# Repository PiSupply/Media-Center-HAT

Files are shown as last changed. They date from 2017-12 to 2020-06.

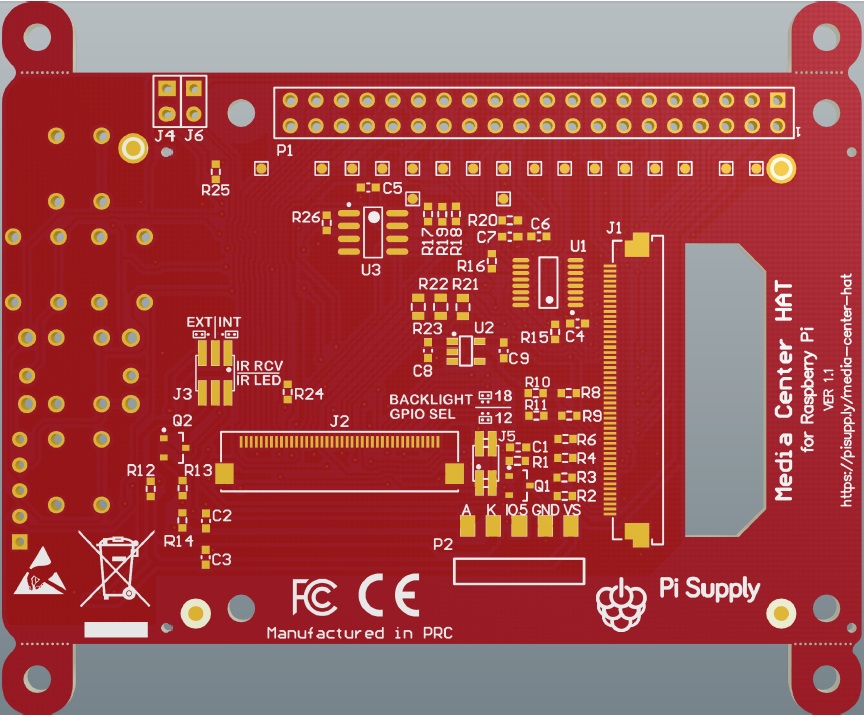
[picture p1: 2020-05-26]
Hardware/Production/MC_HAT_bottom.jpg

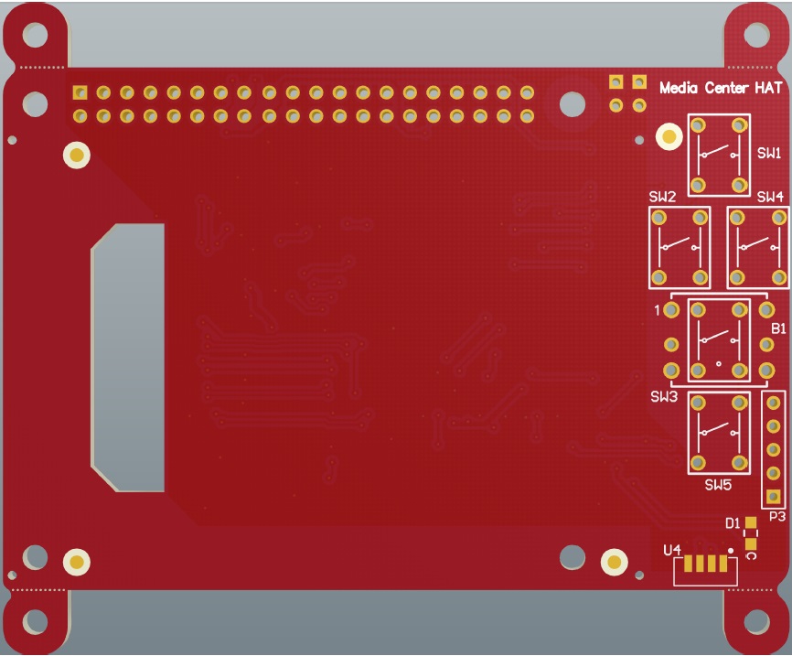
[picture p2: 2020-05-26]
Hardware/Production/MC_HAT_top.jpg

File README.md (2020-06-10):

Media-Center-HAT-Banner
# Media Center HAT
Media-Center-HAT

Take your entertainment with the Raspberry Pi to the next level with the Media Center HAT. Build a full-featured media center capable of playing nearly all of your digital media using any 40-pin Raspberry Pi computer and the Media Center HAT. Native support in OSMC and LibreELEC and other media center operating systems brings plug-n-play compatibility and the 2.83" resistive touchscreen, optional 5-way programmable joystick and included IR remote gives you 3-ways to control your content. Flexible mounting options let you position the HAT for use as is or in an enclosure. Create the Raspberry Pi powered media center you've always wanted with the Media Center HAT.

# Set Up Media Center HAT
## Auto Installation
Just run the following script in a terminal window and the Media Center HAT will be automatically setup.
```bash
# Run this line and the Media Center HAT will be setup and installed
sudo su -c "bash <(wget -qO- https://pisupp.ly/mediacentersoftware)" root
```

Please check the [software](https://github.com/PiSupply/Media-Center-HAT/blob/master/Software) or the [Hardware](https://github.com/PiSupply/Media-Center-HAT/blob/master/Hardware) sections for further information.

# Thank you!

This software and product is based on and uses a number of open source libraries and we wanted to thank the creators here. This product wouldn't be possible without their efforts!

- [Notro FBTFT](https://github.com/notro/fbtft/wiki)
- [Watterott RPi-Display](https://github.com/watterott/RPi-Display)
- [Lirc](http://www.lirc.org/)

# License

Creative Commons Licence

This work is licensed under a [Creative Commons Attribution-ShareAlike 4.0 International License](http://creativecommons.org/licenses/by-sa/4.0/).

## Open Source Hardware

We are proud to say that the Media Center HAT is certified by the [Open Source Hardware Association](https://certification.oshwa.org/uk000009.html) with UID number UK000009. Our certification mark is below:



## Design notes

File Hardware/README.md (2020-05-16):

# Hardware
MCH_Overview MCH Overview

## Switches

### Buttons

*Please note the the 5 ways joystick is alternative to the various push buttons SW1-5 and therefore is connected to the same GPIO pins on the Raspberry Pi.*

* **SW1** GPIO13(PI33) up
* **SW2** GPIO17(PI11) left
* **SW3** GPIO22(PI15) bottom
* **SW4** GPIO26(PI37) right
* **SW5** GPIO27(PI13) enter
* **B1** 5 ways joystick

## Connectors

### Top of the board

* **P3** External rotary encoder

### Bottom of the board

* **P2** External IR receiver and LED
  * **VS** 3.3V source for external IR receiver,
  * **GND** ground connection for external IR receiver,
  * **GPIO5(PI29)** input for external IR receiver,
  * **K** cathode connection for external IR LED transmitter,
  * **A** 5V source for external IR LED transmitter, connects to anode

* **J1** Display connector
* **J2** GPIO adapter

## Jumpers

* **J3** IR selection jumper, on board or external.
    * **1-3** Internal IR receiver
    * **3-5** External IR receiver
    * **2-4** Internal IR LED
    * **4-6** External IR LED
* **J4** ID EEPROM write protect disable jumper. Short to write to EEPROM.
* **J5** Backlight control GPIO selection jumper, GPIO18(PI12) or GPIO12(PI32). The GPIO controlling the backlight defaults to GPIO12 so that the MCH can be used in conjunction with an audio board using I2S like in the case of JustBoom Audio, HiFiBerry, iQaudio, etc.
* **J6** Change ID EEPROM address from 0x50 to 0x51. Short or install a 2 pin header with a jumper to change address to 0x51.

## Pinout

#### P1 pinout
```text
P1
-----------------------------------------------------------------------------------------------------------------------
| 2     4     6     8    10    12    14    16    18    20    22    24    26    28    30    32    34    36    38    40 |
|5V    5V    GND   o     o     +     GND   #     #     GND   #     o     o     #     GND   +     GND   o     o     o  |
|3V3   o     o     o     GND   +     +     +     3V3   o     o     o     GND   #     #     #     +     o     +     GND|
| 1     3     5     7     9    11    13    15    17    19    21    23    25    27    29    31    33    35    37    39 |
-----------------------------------------------------------------------------------------------------------------------

# Used
o Available
+ Can be reused

11 SW1
12 Backlight control
13 SW5
15 SW3
16 Display reset
18 Display Read/Write control
22 Touch controller interrupt signal
27 I2C_SDA to HAT EEPROM
28 I2C_SDL to HAT EEPROM
29 IR Receiver
31 IR Transmitter
32 Backlight control
33 SW1
37 SW4
```

#### P2 Pinout
```text
P2
-------------------------------
| 1     2     3     4     5   |
|VSYS  GND   PI29   K     A   |
-------------------------------
```

#### P3 Pinout
```text
P3
-------------------------------
| 1     2     3     4     5   |
|GND   3V3   PI13  PI15  PI37 |
-------------------------------
```

#### J2 Pinout
```text
J2
------------------------------------------------------------------------------------------------------------------------------------------------------------------------------------------------------------------------------------------------------------
| 1     2     3     4     5     6     7     8     9    10    11    12    13    14    15    16    17    18    19    20    21    22    23    24    25    26    27    28    29    30    31    32    33    34    35    36    37    38    39    40    MF1   MF2 |
|3V3   5V    SDA   5V    SCL   GND   PI7   PI8   GND  PI10  PI11  PI12  PI13  PI14  PI15  PI16   3V3  PI18  PI19   GND  PI21  PI22  PI23  PI24   GND  PI26  PI27  PI28  PI29   GND  PI31  PI32  PI33   GND  PI35  PI36  PI37  PI38   GND  PI40   GND   GND |
------------------------------------------------------------------------------------------------------------------------------------------------------------------------------------------------------------------------------------------------------------
```

#### J3 Pinout
```text
J3
-----------------
| 2     4     6 |
|INT  IRLED  EXT|
|INT  IRREC  EXT|
| 1     3     5 |
-----------------
```

#### J4 Pinout
```text
J4
-------------
| 1     2   |
|3V3   A2/A1|
-------------
```

#### J5 Pinout
```text
J5
------------
| 2     4  |
|PI12   BL |
|PI32   BL |
| 1     3  |
------------
```

#### J6 Pinout
```text
J6
------------
| 1     2  |
|3V3   A0  |
------------
```

#### B1 Pinout
```text
B1
------------------
| 6     5     4  |
|PI13  PI37  GND |
|PI33  PI11  PI15|
| 1     2     3  |
------------------
```

#### TP Pinout
```text
TP
------------------------------------------------------------------------------------------------------------
| 1     2     3     4     5     6     7     8     9    10    11    12    13    14    15    16    17    18  |
|GND   5V    3V3   MOSI  MISO  SCK LCD_CS SEN_CS PI12 PI16  PI18  PI29  PI31 ID_SCL ID_SDA EWP  PI22  PI32 |
------------------------------------------------------------------------------------------------------------
```

## Components

### Main active components

Main ICs

The picture above highlights the main ICs used on the Media Center HAT. Links to the various datasheets have been provided in line with the description.

1. **Display** [MI0283QT](https://github.com/PiSupply/Media-Center-HAT/blob/master/Hardware/Datasheets/MI0283QT-11_Ver1.4.pdf) 2.8" TFT Display(320x240)with Touchpanel.
2. **Touch screen controller** [ADS7846](https://github.com/PiSupply/Media-Center-HAT/blob/master/Hardware/Datasheets/ads7846.pdf) 4-wire touch screen controller.
3. **IR Rcv Module** [TSOP75238W](https://github.com/PiSupply/Media-Center-HAT/blob/master/Hardware/Datasheets/TSOP75238W.pdf) miniaturised SMD IR receiver for infrared remote control systems.
4. **EEPROM** [CAT24C32](https://github.com/PiSupply/Media-Center-HAT/blob/master/Hardware/Datasheets/CAT24C32-D.PDF)  EEPROM, I2C, 32KBIT, 400KHZ, 1V7-5V5

### Unpopulated

You may notice that there are several components which have not be installed on your board. This section aims to explain what they are and which are for user customisation.

* **TPx** these are all test points used to test the boards during manufacturing. Refer to the pinout above for more information.

* **R20** this is hardware configuration of reference input to touch interface chip. This is not important to users. How would use this, if necessary?

* **R21, R22 and R23** It is about to have better signal integrity on high frequency SPI lines by cutting off side connection to header and cable if there for any purpose.
R21, R22 and R23 should be populated if the HAT is connected through J2 40 FPC header to the Raspberry Pi via GPIO adaptor board. These can be zero Ohm resistors or just solder shorts.
    * **R21** SPI MOSI, connects RPI MOSI GPIO to equivalent pin 19 of J2 FPC header,
    * **R22** SPI MISO, connects RPI MISO GPIO to equivalent pin 21 of J2 FPC header,
    * **R23** SPI SCK, connects RPI CLK GPIO to equivalent pin 23 of J2 FPC header.

* **R9, R10** Used for display interface selection.
  * **Unpopulated** default, 4-wire 8-bit data serial SPI interface,
  * **Both populated** 3-wire 9-bit data serial SPI interface.

## Misc
It is possible that EEPROM is not programmed, or is programmed with different DT which does not match GPIO selection jumper default configuration (GPIO12).

The EEPROM should be programmed using dtbo for GPIO12 file from drive. They can try to switch gpio sel jumper to position 18 and see if it works. If not they can try to
enable device tree in config.txt by putting SD into PC, adding two lines:

```text
dtoverlay=gpio-ir,gpio_pin=5
dtoverlay=rpi-display,speed=32000000,rotate=90
```

No additional pullups and resistors on board for buttons/joystick/encoder, just ones enabled at gpio rpi ports. It should be configured as pullups for these, because button on schematic is connected to gnd. Placing additional resistors may constrain to use that gpios for other gpio functions like LEDs or some other output control...so we decided to omit these from the design, to make it more useful in a wider array of use cases. Because of this, you can use the button inputs to just connect to the various GPIO pins for other purposes as well.

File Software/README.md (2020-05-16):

# Media Centre HAT Software

## Software Installation

**NOTE:** When using the Media Center HAT with the PiJuice HAT you will need to change the ID EEPROM address on the PiJuice to 0x52 otherwise both HAT's will conflict with each other and the Media Center HAT will not load the DT overlay file.

### Automated process

Just run the following script in a terminal window and the Media Center HAT will be automatically setup.
```bash
# Run this line and the Media Center HAT will be setup and installed
sudo su -c "bash <(wget -qO- https://pisupp.ly/mediacentersoftware)" root
```

alternatively from the command line:

```bash
git clone https://github.com/PiSupply/Media-Center-HAT.git
sudo bash Media-Centre-HAT/Software/install.sh
```

#### Screen Orientation
```text
Select one of the options below:
[0] - Portrait
[90] - Horizontal (Default)
[180] - Portrait Reverse
[270] - Horizontal Reverse
```
Reply with one of the following values: 0, 90, 180, 270

#### TFT Driver
```text
--- Updating /boot/config.txt ---

Please reboot the system after the installation.

--- Updating /etc/X11/xorg.conf.d ---

-layout TFT
-layout HDMI
-layout HDMITFT
When -layout is not set, the first is used: TFT
```

#### Console
```text
Activate the console on the TFT display? y/n
```
Reply with "Y"

#### Framebuffer (fbcp)
```text
Install fbcp (Framebuffer Copy)? y/n
```
Reply with "Y"

```text
To enable automatic startup of fbcp run:
sudo update-rc.d fbcp defaults
To disable automatic startup of fbcp run:
sudo update-rc.d fbcp remove
```

```text
Enable automatic startup of fbcp on boot? y/n
```
Reply with "Y"

```text
Note: The console output on the TFT display will be disabled.
Set screen blanking time to 10 minutes.
```

#### xinput-calibrator
```text
Install xinput-calibrator? y/n
```
Reply with "Y"

#### Joystick/buttons
```text
Enable onboard Joystick/Buttons? y/n
```
Reply with "Y"

#### MCH IR Remote
```text
Configure MCH IR Remote? y/n
```
Reply with "Y"

#### Reboot
```text
Reboot the system now? y/n
```
Reply with "Y"

### Manual process

#### Changing the screen orientation
If you wish to change the screen orientation without running the installation script you can change the following line in `/boot/config.txt`:

```text
dtoverlay=media-center,speed=32000000,rotate=0
```

and change rotate to 0, 90, 180 or 270.

#### Configure video driver
fbdev is an Xorg driver for framebuffer devices. You need to edit the file `/usr/share/X11/xorg.conf.d` and add the following:
```text
Section "ServerLayout"
    Identifier "TFT"
    Option "BlankTime" "10"
    Screen 0 "ScreenTFT"
EndSection

Section "ServerLayout"
    Identifier "HDMI"
    Option "BlankTime" "10"
    Screen 0 "ScreenHDMI"
EndSection

Section "ServerLayout"
    Identifier "HDMITFT"
    Option "BlankTime" "10"
    Screen 0 "ScreenHDMI"
    Screen 1 "ScreenTFT" RightOf "ScreenHDMI"
#   Screen 1 "ScreenTFT" LeftOf "ScreenHDMI"
#   Screen 1 "ScreenTFT" Above "ScreenHDMI"
#   Screen 1 "ScreenTFT" Below "ScreenHDMI"
#   Screen 1 "ScreenTFT" Relative "ScreenHDMI" x y
#   Screen 1 "ScreenTFT" Absolute x y
EndSection

Section "Screen"
    Identifier "ScreenHDMI"
    Monitor "MonitorHDMI"
    Device "DeviceHDMI"
Endsection

Section "Screen"
    Identifier "ScreenTFT"
    Monitor "MonitorTFT"
    Device "DeviceTFT"
Endsection

Section "Monitor"
    Identifier "MonitorHDMI"
Endsection

Section "Monitor"
    Identifier "MonitorTFT"
Endsection

Section "Device"
    Identifier "DeviceHDMI"
    Driver "fbturbo"
    Option "fbdev" "/dev/fb0"
    Option "SwapbuffersWait" "true"
EndSection

Section "Device"
    Identifier "DeviceTFT"
    Driver "fbturbo"
    Option "fbdev" "/dev/fb1"
EndSection
EOF
```
#### Touchscreen configuration
Edit the file `/usr/share/X11/xorg.conf.d/99-ads7846-cal.conf` and add the following:
```text
Section "InputClass"
  Identifier "calibration"
  MatchProduct "ADS7846 Touchscreen"
  Option "EmulateThirdButton" "1"
  Option "EmulateThirdButtonButton" "3"
  Option "EmulateThirdButtonTimeout" "1500"
  Option "EmulateThirdButtonMoveThreshold" "30"
  Option "InvertX" "$invertx"
  Option "InvertY" "$inverty"
  Option "SwapAxes" "$swapaxes"
  Option "TransformationMatrix" "$tmatrix"
EndSection
EOF
```
Where $invertx, inverty, $swapaxes and $tmatrix is replace with one of the following values depending on the screen orientation:
```text
0 degrees (Portrait)
invertx="0"
inverty="0"
swapaxes="0"
tmatrix="1 0 0 0 1 0 0 0 1"

90 degrees (Horizontal (Default))
invertx="1"
inverty="0"
swapaxes="1"
tmatrix="0 -1 1 1 0 0 0 0 1"

180 degrees (Portrait reverse)
invertx="1"
inverty="1"
swapaxes="0"
tmatrix="-1 0 1 0 -1 1 0 0 1"

270 degrees (Horizontal reverse)
invertx="0"
inverty="1"
swapaxes="1"
tmatrix="0 1 0 -1 0 1 0 0 1"
```

#### Install Xinput Calibrator
Xinput calibrator can be used to fine tune the touchscreen calibration for the screen.

```bash
sudo apt-get install xinput-calibrator -y
```

Point the values recorded of Xinput calibrator to `99-ads7846-cal.conf` file by editing `/etc/X11/Xsession.d/xinput_calibrator_pointercal` and adding the following:
```text
#!/bin/sh
PATH="/usr/bin:$PATH"
BINARY="xinput_calibrator"
CALFILE="/usr/share/X11/xorg.conf.d/99-ads7846-cal.conf"
LOGFILE="/var/log/xinput_calibrator.pointercal.log"

CALDATA=`grep -o 'Option[[:space:]]*"MinX".*' $CALFILE`
if [ ! -z "$CALDATA" ] ; then
    echo "Using calibration data stored in $CALFILE"
    exit 0
fi

CALDATA=`DISPLAY=:0.0 $BINARY --output-type xorg.conf.d --device 'ADS7846 Touchscreen' | tee $LOGFILE | grep -i 'MinX\|MaxX\|MinY\|MaxY'`
if [ ! -z "$CALDATA" ] ; then
    sed -i "/MinX/d;/MaxX/d;/MinY/d;/MaxY/d;/EndSection/d" "$CALFILE"
    cat >> "$CALFILE" <<EOD
$CALDATA
EndSection
EOD
    echo "Calibration data stored in $CALFILE (log in $LOGFILE)"
fi
EOF
```

Add touchpanel calibration to startup by editing `/etc/xdg/lxsession/LXDE-pi/autostart` and add the following line:
```text
sudo /bin/sh /etc/X11/Xsession.d/xinput_calibrator_pointercal
```
#### Update lightdm for Buster
Raspbian Buster uses lightdm to control the X server. We need to edit the `/etc/lightdm/lightdm.conf` file and edit the comment our line:
For TFT only:
`xserver-layout=TFT`

For HDMI only
`xserver-layout=HDMI`

For HDMI with TFT extended
`xserver-layout=HDMITFT`

#### Install fbcp
This program is used to copy the primary framebuffer copy to a secondary framebuffer. Usually to copy the output of the HDMI of the Raspberry Pi to a TFT display.

#### Activate the console
If you are using Raspbian Lite or booting to the command line in the Deskop version then you will need to activate the console display by editing `/boot/cmdline.txt` and add the following at the end of the file:
```text
rootwait fbcon=map:10 fbcon=font:VGA8x8 consoleblank=0
```

#### Configure dtoverlay for the buttons

The default configuration for the buttons and the joystick is to map to the arrow keys and to the enter key. Should you wish to alter the mapping you can change the mapping in `/boot/config.txt`

By default if you have enabled the joystick during install you should find the following:
```text
dtoverlay=gpio-key,gpio=13,keycode=103,label="KEY_UP"
dtoverlay=gpio-key,gpio=17,keycode=105,label="KEY_LEFT"
dtoverlay=gpio-key,gpio=22,keycode=108,label="KEY_DOWN"
dtoverlay=gpio-key,gpio=26,keycode=106,label="KEY_RIGHT"
dtoverlay=gpio-key,gpio=27,keycode=28,label="KEY_ENTER"
```

you can change the keycode and the label according to the [input-event-codes.h](https://github.com/torvalds/linux/blob/v4.12/include/uapi/linux/input-event-codes.h)

You can also temporarily configure the keys at runtime without needing to alter the main configuration file by running a command like:

```bash
sudo dtoverlay gpio-key gpio=13 keycode=59 label="KEY_F1"
```

This will map GPIO13 to the F1 key of the keyboard.

You can check that the mapping is what you expect by using the command line tool `evtest`. Simply install it via `apt-get install evtest` and run it. You will be prompted with something similar to:

```text
No device specified, trying to scan all of /dev/input/event*
Not running as root, no devices may be available.
Available devices:
/dev/input/event0:      1b.button
/dev/input/event1:      1a.button
/dev/input/event2:      16.button
/dev/input/event3:      11.button
/dev/input/event4:      d.button
/dev/input/event5:      ADS7846 Touchscreen
Select the device event number [0-5]:
```
In the case above the first 5 events are registered to each of the buttons.
1b for example is associated with GPIO 27. 0x1B is 27 in decimal, 0x1A is 26 and so on.

You can test each button by choosing the corresponding event from the list.
Press CTRL^C to terminate.

*Note that should you wish to use buttons which are wired in a different way than the ones we provided on the MCH you will need to take in consideration that you will need to use the `gpio_pull` option on the command you run. The default pull=2 is safer, of course, otherwise the line will float which may cause spurious readings. We use gpio_pull=0 because the MCH has hardware pullups and won't need to use the Raspberry Pi ones.*

*Example `sudo dtoverlay gpio-key gpio=21 keycode=4 label="KEY_4" gpio_pull=0` 2:up 1:down 0:none*

## LIRC configuration

Before you begin to install and configure LIRC you need to make sure that the gpio-ir driver is loaded by adding the followig line to the `/boot/config.txt` file:
```bash
dtoverlay=gpio-ir,gpio_pin=5
```

At the command line install Lirc:
```bash
sudo apt-get install lirc
```

Then edit `/etc/lirc/lirc_options.conf` and change:
```text
driver  = devinput
device  = auto
```

to:

```text
driver  = default
device  = /dev/lirc0
```

After a reboot you can test that the IR receiver is properly configured by running (*CTRL^C to interrupt*):

```bash
mode2 --driver default --device /dev/lirc0
```

and start pressing the buttons of a remote. You should get some output on screen like the following:

```text
space 1625
pulse 593
space 1650
pulse 598
space 538
pulse 601
space 1647
pulse 622
space 514
pulse 605
space 1670
pulse 577
space 559
pulse 571
```

You can now proceed to record the configuration of the IR remote you wish to use or use our default ones:
* MCH-1.lircd.conf
* MCH-2.lircd.conf

Save the original configuration file and copy the new one in it's place.
```bash
sudo mv /etc/lirc/lircd.conf /etc/lirc/lircd.conf.org
sudo cp ~/MCH-2.lircd.conf /etc/lirc/lircd.conf
```

Finally restart the service:
```bash
sudo systemctl restart lircd.service
```

### Train a new remote
You can train pretty much any IR remote to work with the MCH.
Run the following command and follow the instructions to generate a new lircd.conf.
```bash
sudo irrecord -n -d /dev/lirc0 ~/lircd.conf
```
Once done you will have to copy it to sudo `/etc/lirc/`

```bash
sudo cp ~/NEW-REMOTE.lircd.conf /etc/lirc/lircd.conf
```
Restart the service to get the new configuration running.

### User the MCH as a remote
With the MCH you can also control other appliances like TV sets, game consoles, media centres, etc.

To find out which IR remotes configurations are available run
```bash
irsend "" "" LIST
```
Then find out which control are available for the remote you intend to use:
```bash
irsend list MCH-2 ""
```
Which will show something like this
```text
0000000000ffa25d Power
0000000000ff629d Enter
0000000000ffe21d Mode
0000000000ff22dd CH-
0000000000ff02fd CH+
0000000000ffc23d EQ
0000000000ffe01f Previous
0000000000ffa857 Next
0000000000ff906f Play/Pause
0000000000ff6897 Vol-
0000000000ff9867 Vol+
0000000000ffb04f 0
0000000000ff30cf 1
0000000000ff18e7 2
0000000000ff7a85 3
0000000000ff10ef 4
0000000000ff38c7 5
0000000000ff5aa5 6
0000000000ff42bd 7
0000000000ff4ab5 8
0000000000ff52ad 9
```

Finally run the control you need:
```bash
irsend SEND_ONCE MCH-2 Power
```

### Troubleshooting
You should be able to check that all is working fine by issuing the following commands:

```bash
lsmod | grep lirc
```
```text
which should return something similar to this
lirc_rpi                9032  0
lirc_dev               10583  1 lirc_rpi
rc_core                24377  1 lirc_dev
```

```bash
ls /var/run/lirc/
```
```text
lircd  lircd.pid  lircm
```

```bash
mode2 --driver default --list-devices
```
```text
/dev/lirc0
```

```bash
dmesg | grep lirc
```
```text
[    3.134395] lirc_dev: IR Remote Control driver registered, major 243
[    3.148485] lirc_rpi: module is from the staging directory, the quality is unknown, you have been warned.
[    4.219536] lirc_rpi: auto-detected active low receiver on GPIO pin 5
[    4.220011] lirc_rpi lirc_rpi: lirc_dev: driver lirc_rpi registered at minor = 0
[    4.220017] lirc_rpi: driver registered!
[    6.345325] input: lircd-uinput as /devices/virtual/input/input1
```

```bash
sudo vcdbg log msg |& grep -v -E "(HDMI|gpioman|clock|brfs)"
```
```text
001444.756: *** Restart logging
001446.035: Read command line from file 'cmdline.txt'
dwc_otg.lpm_enable=0 console=serial0,115200 console=tty1 root=PARTUUID=17d7977b-02 rootfstype=ext4 elevator=deadline fsck.repair=yes rootwait quiet splash plymouth.ignore-serial-consoles
001755.940: Loading 'kernel7.img' to 0x8000 size 0x45e6c8
002069.795: No kernel trailer - assuming DT-capable
002073.619: Loading 'bcm2710-rpi-3-b.dtb' to 0x4666c8 size 0x44d8
002196.868: Loaded HAT overlay
002196.885: dtparam: i2c_arm=on
002206.431: dtparam: spi=off
002352.910: Loaded overlay 'lirc-rpi'
002352.926: dtparam: gpio_in_pin=5
002353.446: dtparam: gpio_out_pin=6
002354.009: dtparam: audio=on
002419.661: Loaded overlay 'rpi-display'
002419.677: dtparam: speed=32000000
002420.719: dtparam: rotate=270
003759.247: Device tree loaded to 0x2effb100 (size 0x4e31)
004897.205: vchiq_core: vchiq_init_state: slot_zero = 0xfad80000, is_master = 1
004906.638: TV service:host side not connected, dropping notification 0x00000002, 0x00000002, 0x00000009
```

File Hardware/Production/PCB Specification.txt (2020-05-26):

Board properties:
	2 Layers Standard Stackup
	Width: 85 mm
	Height: 70.5 mm
	Finished Thickness: 2 mm

Layers:
	Silkscreen top
	Top Solder mask
	Copper Top - 35um
	FR4 ~ 1.9 mm
	Copper Bottom - 35um
	Bottom Solder mask
	Silkscreen bottom
	
Smallest structures:
	Track width: 0.25 mm
	Spacing: 0.25 mm
	Hole size: 0.3 mm
	Via Pad size: 0.8 mm

Solder mask colour: Red
Silk screen colour: White

FR4 TG >=135 °C
ENIG finish

PCB Manufacturing files:

FILE NAME 		DESCRIPTION			FILE TYPE

TopLayer.GTL		Top Copper Layer		Gerber
BottomLayer.GBL		Bottom Copper Layer		Gerber
SolderMaskTop.GTS	Solder mask top side		Gerber
SolderMaskBottom.GBS	Solder mask bottom side		Gerber
SilkscreenTop.GTO	Silkscreen top side		Gerber
SilkscreenBottom.GBO	Silkscreen Bottom side		Gerber
DrillDrawing.GD1	Drill Drawing Plots		Gerber
DrillGuide.GG1		Drill Guide Plots		Gerber
NcDrillRoundHoles.TXT	NC Drill for round holes	Text
NcDrillSlotHoles.TXT	NC Drill for slot holes		Text
Keepout.GKO		Board Cut definition		Gerber
Aperture.apr		Aperture definition

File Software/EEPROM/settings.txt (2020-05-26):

########################################################################
# EEPROM settings text file
#
# Edit this file for your particular board and run through eepmake tool,
# then use eepflash tool to write to attached HAT ID EEPROM 
#
# Tools available:
#  eepmake   Parses EEPROM text file and creates binary .eep file
#  eepdump   Dumps a binary .eep file as human readable text (for debug)
#  eepflash  Write or read .eep binary image to/from HAT EEPROM
#
########################################################################

########################################################################
# Vendor info

# 128 bit UUID. If left at zero eepmake tool will auto-generate
# RFC 4122 compliant UUID
product_uuid f028d540-fd17-4c31-ba5a-000000000000

# 16 bit product id
product_id 0x0002

# 16 bit product version
product_ver 0x0101

# ASCII vendor string  (max 255 characters)
vendor "Pi Supply"

# ASCII product string (max 255 characters)
product "Media Center HAT"

########################################################################
# GPIO bank settings, set to nonzero to change from the default.
# NOTE these setting can only be set per BANK, uncommenting any of
# these will force the bank to use the custom setting.

# drive strength, 0=default, 1-8=2,4,6,8,10,12,14,16mA, 9-15=reserved
gpio_drive 0

# 0=default, 1=slew rate limiting, 2=no slew limiting, 3=reserved
gpio_slew 0

# 0=default, 1=hysteresis disabled, 2=hysteresis enabled, 3=reserved
gpio_hysteresis 0

# If board back-powers Pi via 5V GPIO header pins:
# 0 = board does not back-power
# 1 = board back-powers and can supply the Pi with a minimum of 1.3A
# 2 = board back-powers and can supply the Pi with a minimum of 2A
# 3 = reserved
# If back_power=2 then USB high current mode will be automatically 
# enabled on the Pi
back_power 0

########################################################################
# GPIO pins, uncomment for GPIOs used on board
# Options for FUNCTION: INPUT, OUTPUT, ALT0-ALT5
# Options for PULL: DEFAULT, UP, DOWN, NONE
# NB GPIO0 and GPIO1 are reserved for ID EEPROM so cannot be set

#         GPIO  FUNCTION  PULL
#         ----  --------  ----
#setgpio  2     INPUT     DEFAULT
#setgpio  3     INPUT     DEFAULT
#setgpio  4     INPUT     DEFAULT
#setgpio  5     INPUT     DEFAULT
#setgpio  6     INPUT     DEFAULT
#setgpio  7     INPUT     DEFAULT
#setgpio  8     INPUT     DEFAULT
#setgpio  9     INPUT     DEFAULT
#setgpio  10    INPUT     DEFAULT
#setgpio  11    INPUT     DEFAULT
#setgpio  12    INPUT     DEFAULT
setgpio  13    INPUT     UP
#setgpio  14    INPUT     DEFAULT
#setgpio  15    INPUT     DEFAULT
#setgpio  16    INPUT     DEFAULT
setgpio  17    INPUT     UP
#setgpio  18    INPUT     DEFAULT
#setgpio  19    INPUT     DEFAULT
#setgpio  20    INPUT     DEFAULT
#setgpio  21    INPUT     DEFAULT
setgpio  22    INPUT     UP
#setgpio  23    INPUT     DEFAULT
#setgpio  24    INPUT     DEFAULT
#setgpio  25    INPUT     DEFAULT
setgpio  26    INPUT     UP
setgpio  27    INPUT     UP

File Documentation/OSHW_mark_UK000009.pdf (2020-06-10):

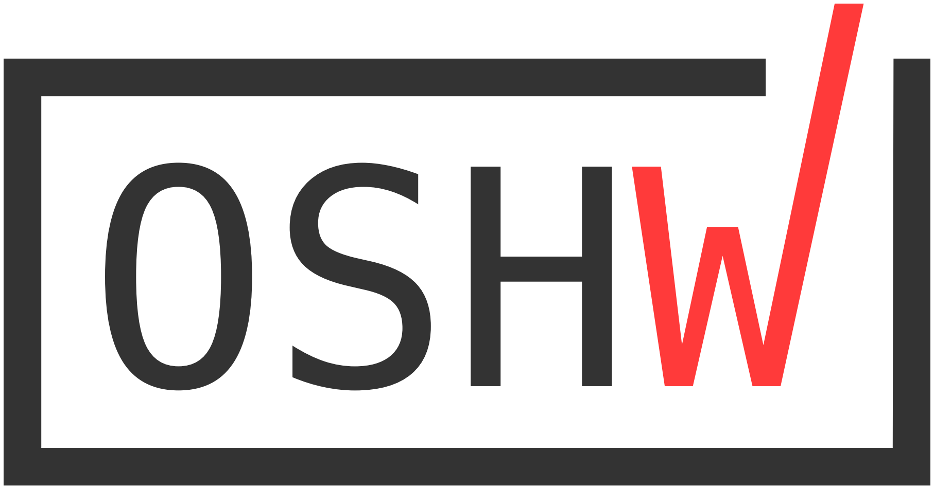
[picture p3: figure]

UK000009

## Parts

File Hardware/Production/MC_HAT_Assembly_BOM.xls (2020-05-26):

Designator | Layer | Part Number | Description | Mounting | Package | Dimensions(LxWxH) | ROHS | Peak Reflow Duration | Peak Reflow Temp. | Quantity | Note
C1, C2, C4, C5, C6, C7 | Bottom | C0603C104K5RACTU | 100nF,X7R,50V,10% | SM | 0603 | 1,6 x 0,8 x 0,8 mm | True | 10 | 260 | 6
C3, C8, C9 | Bottom | C1608X6S1A475K080AC | 4.7uF,X6S,10%,10V. | SM | 0603 | 1,6 x 0,8 x 0,9 mm | True | 10 | 260 | 3
J1 | Bottom | 62684-50210E9ALF | FFC,top,N50,P0.5mm,T0.3mm. | SM | SM-50 | 30,5 x 5,6 x 2 mm | True | 10 | 260 | 1
J2 | Bottom | FP520Q-40SR04 | FPC,N40,P0.5,T0.3. | SM | SM-40 | 23,95 x 4,9 x 2 mm | False |  |  | 1
J3 | Bottom | 20021121-00006C4LF | Header 2x3,SMD,1,27mm | SM | SM-6 | 3,81 x 5,5 x 5,5 mm | True | 10 | 260 | 1
J5 | Bottom | 20021121-00004C4LF | Header, 2x2,SMD,1.27mm. | SM | SM-4 | 2,54 x 5,5 x 5,5 mm | True | 10 | 260 | 1
P1 | Bottom | 20924 | Board-To-Board,N40,H=15mm,DIP=3.5mm,2row,2.54mm. | SM | HEADER-2x20 | 51,3 x 5 x 15 mm | True |  |  | 1
P2 | Bottom | P101-1*05VT1-130-ND | Header,Right angle,N5,2.54mm. | SM | SM-5 | 12,7 x 12,88 x 2,5 mm | True | 10 | 260 | 1
Q1, Q2 | Bottom | BSH108,215 | NMOS,1.9A,30V,0.077?. | SM | SOT23 | 3 x 2,5 x 1,1 mm | True | 10 | 260 | 2
R1, R8, R11, R16, R26 | Bottom | CRCW060344K2FKEA | 44.2KOhm,0.1W,1%,0603. | SM | 0603 | 1,55 x 0,8 x 0,5 mm | True | 10 | 260 | 5
R13, R14 | Bottom | CRGH0603F39R | 39Ohm,0.2W,50V,1%,0603. | SM | 0603 | 1,6 x 0,8 x 0,45 mm | True | 10 | 260 | 2
R17, R18, R19, R24, R25 | Bottom | CRGH0603F3K9 | 3.9kOhm,0.2W,1%,0603. | SM | 0603 | 1,6 x 0,75 x 0,45 mm | True | 10 | 260 | 5
R2, R3, R4, R6, R12, R15 | Bottom | CRGH0603J47R | 47?,0.2W,5%,50V. | SM | 0603 | 1,6 x 0,6 x 0,5 mm | True | 10 | 260 | 6
U1 | Bottom | ADS7846E | Resistive touch ctrl,4-wire,SPI,I2C,2V2-5V25,50mA. | SM | SSOP-16 | 5 x 6,2 x 1,75 mm | True | 10 | 260 | 1
U2 | Bottom | LP5907MFX-3.3/NOPB | LDO,3V3,250mA,2.2-5.5Vin. | SM | SOT-23 | 3 x 3 x 1,45 mm | True | 10 | 260 | 1
U3 | Bottom | CAT24C32WI-GT3 | EEPROM,I2C,32KBIT,400KHZ,1V7-5V5. | SM | SOIC-8 | 5 x 6,2 x 1,75 mm | True | 10 | 260 | 1
D1 | Top | KP-2012F3C | IR LED,940nm,120 °, 0805, 20 mA, 1.6 V. | SM | 0805 | 2 x 1,25 x 1,1 mm | True | 10 | 260 | 1
U4 | Top | TSOP75438WTT | IR Receiver,38 kHz, 30m, 75 °, 5.5 V, 2.5 V. | SM | SOP4 | 6,8 x 3 x 2,35 mm | True | 10 | 260 | 1
LCD | Top | MI0283QT-11 | LCD module |  |  | 69, 3 x 50,2 x 4 |  |  |  | 1 | Assembled by fitting LCD stubs into PCB holes
 | Bottom | M50-2000005 | Jumper, 1.27mm |  |  |  |  |  |  | 3 | Use assembly image from bottom to put jumpers in default position.

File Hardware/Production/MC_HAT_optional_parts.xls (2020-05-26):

Designator | Layer | Part Number | Description | Mounting | Package | Dimensions(LxWxH) | Quantity | Note
SW1, SW2, SW3, SW4, SW5 | Top | DTS63N | Pushbutton, SPST-NO, h=7mm | TH | TH-4 | 6 x 6 mm | 5
B1 | Top | SKQUCAA010 | Navigation switch (Joystick),4 direction&pushbut,0.05A,12VDC. | TH | TH6 | 10 x 10 x 10 mm | 1
 |  | OED-EL-1L2 | Infrared (IR) Emitter 940nm 1.2V 100mA 60mW/sr @ 100mA 60° Radial | TH | Radial |  | 2 | Wiring through P2 Header, two in series connection.
 |  | TSOP4438 | Infrared Receivers 2.5-5.5V 38kHz 45Deg | TH-3 |  |  | 1 | Wiring through P2 Header.

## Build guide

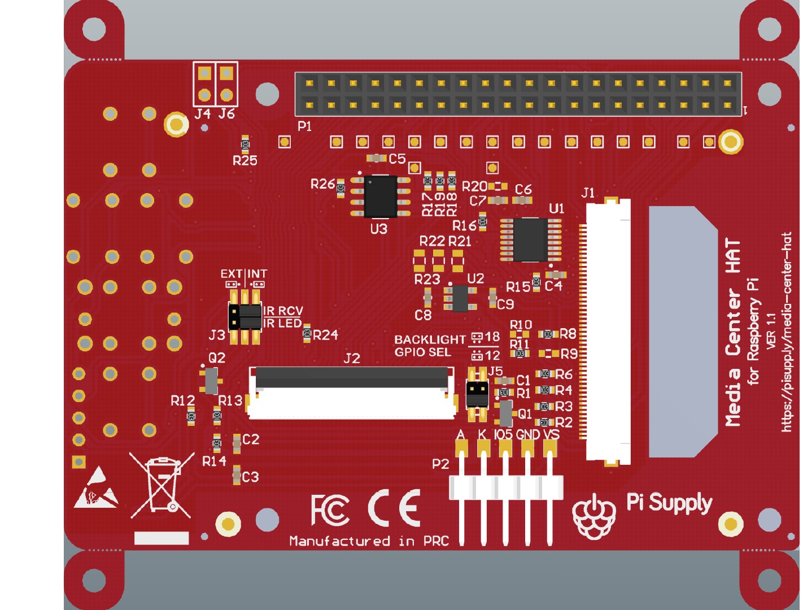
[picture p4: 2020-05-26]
Hardware/Production/MC_HAT_Assembly_bottom.jpg

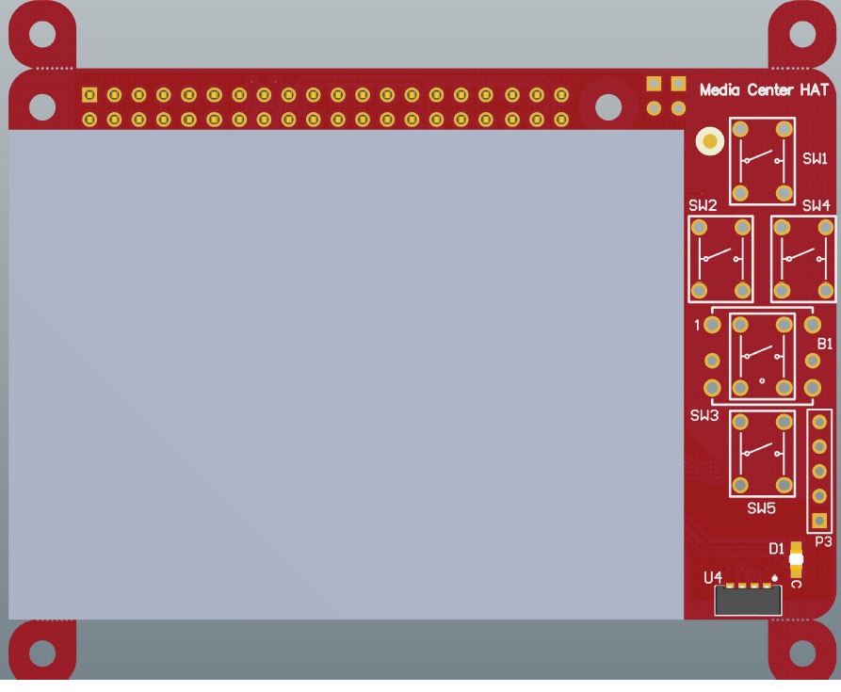
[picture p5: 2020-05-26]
Hardware/Production/MC_HAT_Assembly_top.jpg

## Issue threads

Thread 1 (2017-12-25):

Configure joystick / buttons using overlay?

shawaj, 2017-12-25:
See here - https://github.com/notro/fbtft/blob/master/dts/overlays/rpi/tinylcd35-overlay.dts

shawaj, 2018-01-13:
Have sorted this in https://github.com/raspberrypi/linux/pull/2329

So can probably build this into the install scripts now pretty easily

shawaj, 2018-01-29:
Maybe as a yes / no question in the installer I'm not sure?

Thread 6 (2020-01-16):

Install setup isn't working

ryanteck, 2020-01-16:
Running the command from the github doesn't work out of the box as it expects an option to be selected.

Downloading the bash program then running it works,

Other issues are:
```dpkg-deb: error: 'xinput-calibrator_0.7.5-1_armhf.deb' is not a Debian format archive```

After doing it I couldn't get an x window to display and only got a backlight turning on.

```pi@raspberrypi:~ $ sudo bash mediacentersoftware
Select one of the options below:
[0] - Portrait
[90] - Horizontal (Default)
[180] - Portrait Reverse
[270] - Horizontal Reverse
90
Enable TFT display driver and activate X windows on TFT display? y/n y
--- Updating /boot/config.txt ---

Please reboot the system after the installation.

--- Updating /etc/X11/xorg.conf.d ---

startx -- -layout TFT
startx -- -layout HDMI
startx -- -layout HDMITFT
When -layout is not set, the first is used: TFT

Activate the console on the TFT display? y/n y
sed: can't read /etc/kbd/config: No such file or directory
Install fbcp (Framebuffer Copy)? y/n y
--- Installing fbcp ---
Reading package lists... Done
Building dependency tree
Reading state information... Done
build-essential is already the newest version (12.6).
cmake is already the newest version (3.13.4-1).
git is already the newest version (1:2.20.1-2+deb10u1).
0 upgraded, 0 newly installed, 0 to remove and 0 not upgraded.
Cloning into 'rpi-fbcp'...
remote: Enumerating objects: 7, done.
remote: Counting objects: 100% (7/7), done.
remote: Compressing objects: 100% (5/5), done.
remote: Total 7 (delta 1), reused 6 (delta 1), pack-reused 0
Unpacking objects: 100% (7/7), done.
-- The C compiler identification is GNU 8.3.0
-- The CXX compiler identification is GNU 8.3.0
-- Check for working C compiler: /usr/bin/cc
-- Check for working C compiler: /usr/bin/cc -- works
-- Detecting C compiler ABI info
-- Detecting C compiler ABI info - done
-- Detecting C compile features
-- Detecting C compile features - done
-- Check for working CXX compiler: /usr/bin/c++
-- Check for working CXX compiler: /usr/bin/c++ -- works
-- Detecting CXX compiler ABI info
-- Detecting CXX compiler ABI info - done
-- Detecting CXX compile features
-- Detecting CXX compile features - done
-- Configuring done
-- Generating done
-- Build files have been written to: /tmp/rpi-fbcp/build
Scanning dependencies of target fbcp
[ 50%] Building C object CMakeFiles/fbcp.dir/main.c.o
[100%] Linking C executable fbcp
[100%] Built target fbcp
  % Total    % Received % Xferd  Average Speed   Time    Time     Time  Current
                                 Dload  Upload   Total   Spent    Left  Speed
100  161k    0  161k    0     0   103k      0 --:--:--  0:00:01 --:--:--  103k
To enable automatic startup of fbcp run:
sudo update-rc.d fbcp defaults
To disable automatic startup of fbcp run:
sudo update-rc.d fbcp remove
Enable automatic startup of fbcp on boot? y/n y
Note: The console output on the TFT display will be disabled.
sed: can't read /etc/kbd/config: No such file or directory

Set screen blanking time to 10 minutes.

Install xinput-calibrator? y/n y
--- Installing xinput-calibrator ---

Run 'sudo startx' to calibrate the touchscreen for X.

  % Total    % Received % Xferd  Average Speed   Time    Time     Time  Current
                                 Dload  Upload   Total   Spent    Left  Speed
100   196  100   196    0     0   1704      0 --:--:-- --:--:-- --:--:--  1719
dpkg-deb: error: 'xinput-calibrator_0.7.5-1_armhf.deb' is not a Debian format archive
dpkg: error processing archive xinput-calibrator_0.7.5-1_armhf.deb (--install):
 dpkg-deb --control subprocess returned error exit status 2
Errors were encountered while processing:
 xinput-calibrator_0.7.5-1_armhf.deb
Install tslib (touchscreen library)? y/n y
--- Creating /dev/input/touchscreen ---
--- Installing tslib ---

Run the following command to calibrate the touchscreen for tslib.
TSLIB_FBDEVICE=/dev/fb1 TSLIB_TSDEVICE=/dev/input/touchscreen sudo ts_calibrate

Reading package lists... Done
Building dependency tree
Reading state information... Done
E: Unable to locate package tslib
Enable onboard Joystick/Buttons? y/n y
--- Configuring Joystick/Buttons ---

Reboot the system now? y/n y
Rebooting now...
Connection to 192.168.0.171 closed by remote host.
Connection to 192.168.0.171 closed.```

ryanteck, 2020-01-16:
Ok so re-started using Normal Raspbian as it failed on Raspbian Lite (I hoped to use it as a terminal).

X Is working on it fine. However the touchscreen calibration still didn't install and the same error with the curl method.

shawaj, 2020-01-16:
I think @tvoverbeek mentioned an issue before with X to @ChristopherRush

tvoverbeek, 2020-01-16:
Yes, instructions are old and not applicable to current Raspbian and X. Also the IR stuff (keycodes) is different in later linux versions.

shawaj, 2020-01-16:
@ChristopherRush can you look at updating before we start shipping at mid to end of February?

ryanteck, 2020-01-16:
I actually re-tested on a normal Raspbian install and it seems to work all fine now. It'll just be the touchscreen calibration that needs fixing which I can do.

tvoverbeek, 2020-01-16:
@ryanteck Yes, screen works, but combining this with normal HDMI does not.
Also the rpi-update mentioned in the instructions will  probably install an old kernel which does not run on a Pi4.
The install is a straight copy from the Waterott instructions for Raspbian Wheezy (I believe).
The way how X is handled is completely wrong (startx is not used any more).
Needs a complete overhaul. Also decide how to use the TFT, as main display or as additional display next to the HDMI.
After all it is called Media-HAT, which I believe means the media are displayed on a large screen (HDMI).
Again most of the IR stuff is now part of the kernel. Lirc is probably not needed any more.

In short: fixing the installation properly will take more time as you might expect.

ryanteck, 2020-01-16:
Indeed most does seem out of date so a majority of it will need to be re-written. However for now I have it working on a 3A+ as the screen only :)

shawaj, 2020-01-16:
@ryanteck @tvoverbeek the general idea is to have it either alongside the HDMI or to use as the only screen. So it was supposed to be configurable

ChristopherRush, 2020-01-16:
@shawaj Will try and sort it out over this weekend.

ChristopherRush, 2020-02-05:
@tvoverbeek @ryanteck I've hit a stumbling block with the following. I am able to run the script `xinput_calibrator_pointercal` manually without any issues but when I add it to `autostart` it doesn't save the values to the `99-ads7846-cal.conf` file.
```bash
function install_xinputcalibrator()
{
  echo "--- Installing xinput-calibrator ---"
  echo

  cd ~
  sudo apt-get install libx11-dev libxext-dev libxi-dev x11proto-input-dev -y
  wget http://github.com/downloads/tias/xinput_calibrator/xinput_calibrator-0.7.5.tar.gz
  tar -zxvf xinput_calibrator-0.7.5.tar.gz
  rm xinput_calibrator-0.7.5.tar.gz
  cd xinput_calibrator-0.7.5
  ./configure
  make
  sudo make install
  cd ~
  rm -r xinput_calibrator-0.7.5

  filename="/etc/X11/Xsession.d/xinput_calibrator_pointercal"
  if [ ! -f $filename ]
  then
      touch $filename
  fi

  cat > /etc/X11/Xsession.d/xinput_calibrator_pointercal <<'EOF'
#!/bin/sh
PATH="/usr/bin:$PATH"
BINARY="xinput_calibrator"
CALFILE="/usr/share/X11/xorg.conf.d/99-ads7846-cal.conf"
LOGFILE="/var/log/xinput_calibrator.pointercal.log"

CALDATA=`grep -o 'Option[[:space:]]*"MinX".*' $CALFILE`
if [ ! -z "$CALDATA" ] ; then
    echo "Using calibration data stored in $CALFILE"
    exit 0
fi

CALDATA=`DISPLAY=:0.0 $BINARY --output-type xorg.conf.d --device 'ADS7846 Touchscreen' | tee $LOGFILE | grep -i 'MinX\|MaxX\|MinY\|MaxY'`
if [ ! -z "$CALDATA" ] ; then
    sed -i "/MinX/d;/MaxX/d;/MinY/d;/MaxY/d;/EndSection/d" "$CALFILE"
    cat >> "$CALFILE" <<EOD
$CALDATA
EndSection
EOD
    echo "Calibration data stored in $CALFILE (log in $LOGFILE)"
fi
EOF

  # add touchpanel calibration to LXDE autostart
  if [ -f "/etc/xdg/lxsession/LXDE-pi/autostart" ]; then
    if grep -q "xinput_calibrator_pointercal" "/etc/xdg/lxsession/LXDE-pi/autostart"; then
      echo "xinput_calibrator already in LXDE autostart"
    else
      cat >> /etc/xdg/lxsession/LXDE-pi/autostart <<'EOF'
@sh /etc/X11/Xsession.d/xinput_calibrator_pointercal
EOF
    fi
  fi
}
```

tvoverbeek, 2020-02-05:
When you run the script from autostart you run as the logged-in user and you cannot write  to CALFILE.
The idea is to run the install-xinputcalibrator function as root which then also runs the calibrator (as root) and creates the CALFILE.
When /etc/X11/Xsession.d/xinput_calibrator_pointercal is called from autostart it will find the calibration data and use them.

tvoverbeek, 2020-02-05:
In addition the install-xinputcalibrator function builds xinput-calibrator-0.7.5 from source while 0.7.5 is available as a package in Raspbian/Debian. No need to build it.

ChristopherRush, 2020-02-06:
The function `install_xinputcalibrator()` is run as user `pi` with command `sudo` for the media center install bash script. Full script is here - https://github.com/ChristopherRush/Media-Center-HAT/blob/master/Software/install.sh

tvoverbeek, 2020-02-06:
There is a conflict. On line 208 /usr/share/X11/xorg.conf.d/99-ads7846-cal.conf is already created.
So xinput_calibrator_pointercal immediately exits (line 260)
It is a while ago I looked at this. Maybe xinput-calibrator is not needed anymore.
I only remember the original Waterott install routine is not applicable to the recent Raspbian versions (Stretch, Buster)

ChristopherRush, 2020-02-13:
@ryanteck @shawaj @tvoverbeek I think i'm about done with the install script now if you would like to test it out. I tested it on Raspbian Buster and Lite, RetroPie, OSMC so far. Feel free to tidy code and make any adjustments.

`sudo su -c "bash <(wget -qO- https://pisupp.ly/test)" root`

ryanteck, 2020-02-13:
I'll test this out shortly on mine 👍

On Thu, Feb 13, 2020 at 9:14 AM Christopher Rush <notifications@github.com>
wrote:

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

--
Ryan WalmsleyEngineer

Pi Supply Unit 4 Bells Yew Green Business Court,
Bells Yew Green, East Sussex, TN3 9BJ, United Kingdom
Email us at sales@pi-supply.com
[image: Pi-Supply] <http://pi-supply.com/>

ryanteck, 2020-02-13:
Seems to work fine on my Pi now we're using FBCP

tvoverbeek, 2020-02-13:
@ChristopherRush Will test after I finish the PiJuice 1.6 packages.

ChristopherRush, 2020-02-19:
Just spotted an issue when selecting TFT only, when HDMI is removed TFT becomes /dev/fb0 so must be changed in the config file from /dev/fb1. Will fix.

ChristopherRush, 2020-04-01:
@tvoverbeek Did you manage to take a look at this at all?

jsteele-cnn, 2020-05-16:
I wasn't able to find this option in the RetroPie menu either, so your instructions may be based on an previous version: `Once in the RetroPie GUI, choose [Manage packages] > [driver].`
I'm reimaging my sd card, and then I'm going to reinstall/configure everything from scratch.
I'm not currently able to connect the controller I was sent as part of the reward to the pi at this time though.

ChristopherRush, 2020-05-26:
Any new problems open up a new git issue. Closing.

Closed 2020-05-26.

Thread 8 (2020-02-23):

Change capacitive to resistive

shawaj, 2020-02-23:
@ryanteck mentioned that we had incorrectly listed that the touch screen is capacitive rather than resistive in documentation and on the product descriptions and packaging. Need to update this

ryanteck, 2020-02-23:
Updated the github

shawaj, 2020-02-23:
Thanks @ryanteck

Will work with @JohnWhiting to update on the packaging and the website 👌

shawaj, 2020-02-29:
Added to Trello for @louisreed on the packaging and I just went to update the website just now and someone has already done it so will close this issue 👌

Closed 2020-02-29.

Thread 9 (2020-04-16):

Update DT overlay to load gpio-ir

ChristopherRush, 2020-04-16:

shawaj, 2020-04-18:
Is this on the eeprom we need to update it?

Here it is for reference https://github.com/raspberrypi/linux/blob/rpi-4.19.y/arch/arm/boot/dts/overlays/media-center-overlay.dts

tvoverbeek, 2020-04-18:
@shawaj @ChristopherRush Yes, the dts references lirc-rpi and lirc-pins.
lirc is outdated. Most of it ca now be done with the media framework which is part of the kernel.
The lirc-rpi module is no longer included in Buster.

ChristopherRush, 2020-04-20:
I have added the overlay to the config.txt during the install process for the time being.

shawaj, 2020-04-20:
Ahh ok - I guess we need to change the overlap in the main rpi repo then?

tvoverbeek, 2020-04-20:
@shawaj Yes, More important which overlay is programmed in the Media HAT EEPROMs?

shawaj, 2020-04-20:
@tvoverbeek the one in the eeprom currently is the GPIO 12 one. Using lirc.

Should have the final boards in about a week or two

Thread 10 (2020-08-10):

White Screen on Raspios

ryanteck, 2020-08-10:
Need to investigate unless something has changed, currently I'm getting just a white screen on Raspios May.

shawaj, 2020-10-02:
For reference https://github.com/raspberrypi/linux/commit/b7d685c0b1bd1b98af0e9c1f5d43769982bdbfb2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

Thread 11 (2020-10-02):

Test with 5.4 kernels

shawaj, 2020-10-02:
As per this issue...

https://github.com/PiSupply/PaPiRus/issues/215

ryanteck, 2020-10-02:
It didn't work and needs fixing.

ryanteck, 2020-10-02:
Duplicate of #10 irc

shawaj, 2020-10-02:
For reference https://github.com/raspberrypi/linux/commit/b7d685c0b1bd1b98af0e9c1f5d43769982bdbfb2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

tvoverbeek, 2020-10-19:
Just tested the changes Phil made in https://github.com/raspberrypi/linux/commit/b7d685c0b1bd1b98af0e9c1f5d43769982bdbfb2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.
They make the screen work again. With the current overlay I only get a black screen with back-light off (The point-shoot cam still takes pictures).
The changes are not yet in the normal repository.

For now to disable the current HAT overlay add the line `dtoverlay=` before any dtparam and dtoverlay lines in /boot/config.txt. This prevents the HAT overlay from loading (No need for soldering the address jumper for address 0x51).
For now you will have to compile the changed overlay your self, copy it to /boot/overlays and put a dtoverlay line in /boot/config.txt
For the future we should use the idea Phil suggested to put only the overlay name in the HAT, so it will always use the current one in /boot/overlays.

shawaj, 2020-10-20:
@tvoverbeek yes I agree, will move to the overlay name method for all production going forward. Need to perform some tests with our production eeprom programmers but relatively trivial to fix if there's an issue anyway

ryanteck, 2020-11-11:
What did we need to do to get this sorted then? Update the script to modify config?

tvoverbeek, 2020-11-11:
@ryanteck
For Media Center Hats with the devicetree fragment in the EEPROM do the following:
- In /boot/config.txt before any dtoverlay lines put the line `dtoverlay=`.
  This prevents the loading of the HAT device tree fragment (which does not work due to changes with SPI in the 5.4 kernel)..
- Further down add the line `dtoverlay=media-center`. This will load the dtoverlay from /boot/overlays.
  The current one is fixed for the SPI communication with the media-center hat.
This works for me.

shawaj, 2021-01-03:
@ryanteck shall we edit the install script to handle this?

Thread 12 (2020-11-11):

Media Center Hat not working on RPi 3B+ and Raspberry Pi OS (Buster installed 2020-11-10)

Danish-Food-Informatics, 2020-11-11:
Hi,

After going through the installation process on a fresh copy of Raspberry Pi OS, using the instructions and installation script (https://learn.pi-supply.com/make/getting-started-with-the-media-center-hat/) and reboot, the display is black (showing nothing).
It shows a white screen for a short while (a second or so) during boot, then black screen.

If I move the mouse, the cursor becomes visible for a second, then black again. It seems like a small square of the desktop turns up at the same time, then turns of again.
There is a small dot of a few bright pixels showing in the upper left hand corner – otherwise black, if the mouse is not moved.
There is seems to be a static sound from the display during boot.

I am using  a Raspberry Pi 3B+, latest version of Raspberry Pi OS (installed 2020-11-10). The same RPi works well with other TFT displays.
The power supply is 5V@3A, which also works well with other RPi 3B+ with displays. No low power/voltage indication.
I have tried a genuine RPi PSU – same problem. So I ruled out the PSU to be the reason.

Help?

ryanteck, 2020-11-11:
Hi @Danish-Food-Informatics , we're working on resolving this issue and hope to have it fixed soon. I believe we're in the final stages of resolving it.

Related to #10 and #11

shawaj, 2020-11-11:
@Danish-Food-Informatics have a look here for the fix https://github.com/PiSupply/Media-Center-HAT/issues/11#issuecomment-725460628

Danish-Food-Informatics, 2020-11-12:
Hi, the fix #11 does not help at all, the problem is still the same:
Black display, if mouse or keyboard id not touched - blinking cursor when mouse is moved, (very) small parts of the screen get visible under the cursor for a second or so, then black screen.

ryanteck, 2020-11-12:
Ho @Danish-Food-Informatics could you take a couple of pictures of the screen to try and show us the issue?

I'll set-up my one tomorrow and see if I can replicate it.

Danish-Food-Informatics, 2020-11-13:
Hi Ryan,
Picture won't do, you will only see a "black" screen :-)
I have made a video of the start-up sequence with no movement of the mouse, then I move the mouse around (at 00:30), then I stop moving the mouse (at about 01:00).
As it cannot be attached here, I have uploaded it to http://www.danfood.info/Download/20201113_092536.mp4
Hope it helps.
Anders

ryanteck, 2020-11-13:
Hi Anders,

for some reason that video isn't playing for me. Could you possibly upload it to youtube as an unlisted video and share the link in a new comment?

Thanks

Danish-Food-Informatics, 2020-11-13:
Try again – it should work now, it does here.

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

tvoverbeek, 2020-11-13:
@Danish-Food-Informatics Looks like you have 2 competing apps wanting to use the display.
Do you by chance have fbcp running?. Try to run without it.
Smells like fbcp is copying a black screen to the SPI display and your app is trying to display its own.

Danish-Food-Informatics, 2020-11-13:
Hi tvoverbeek,
It is a fresh installation of Raspberry Pi OS created with Raspberry Pi Imager (2020-11-10), and the display is installed using the PiSupply instructions and installation script (https://learn.pi-supply.com/make/getting-started-with-the-media-center-hat/) with subsequent reboot.
I have made no other changes or changed any settings or installations - I  have tried twice, with two different microSD card - no difference, the result is the same as shown in the movie both times.

tvoverbeek, 2020-11-13:
If you installed with the Raspberry Pi Imager you got the 2020-08-19 version of the kernel with associated overlays.
The media-center overlay in this version does not work due to SPI changes in the 5.4 kernels.
Look at the output from `apt policy raspberrypi-kernel`
Mine looks as follows:
```
pi@rpi-pj-mch:~ $ apt policy raspberrypi-kernel
raspberrypi-kernel:
  Installed: 1.20201022-1
  Candidate: 1.20201022-1
  Version table:
 *** 1.20201022-1 500
        500 http://archive.raspberrypi.org/debian buster/main armhf Packages
        100 /var/lib/dpkg/status
pi@rpi-pj-mch:~ $
```
an other check you can do is to look at the output from `uname -a` which shows the kernel version.
Here is mine:
```
pi@rpi-pj-mch:~ $ uname -a
Linux rpi-pj-mch 5.4.72-v7+ #1356 SMP Thu Oct 22 13:56:54 BST 2020 armv7l GNU/Linux
pi@rpi-pj-mch:~ $
```

You need the 2020-10-22 version. This has the corrected media-center overlay.
Run 'sudo apt update; sudo apt upgrade` if needed.

Danish-Food-Informatics, 2020-11-13:
Thank you.

Here is the info from my RPi:

pi@raspberrypi:~ $ apt policy raspberrypi-kernel
raspberrypi-kernel:
  Installed: 1.20201022-1
  Candidate: 1.20201022-1
  Version table:
 *** 1.20201022-1 500
        500 http://archive.raspberrypi.org/debian buster/main armhf Packages
        100 /var/lib/dpkg/status
pi@raspberrypi:~ $ uname -a
Linux raspberrypi 5.4.72-v7+ #1356 SMP Thu Oct 22 13:56:54 BST 2020 armv7l GNU/Linux
pi@raspberrypi:~ $

However, it is exactly the same as on your RPi as far as I can see.

tvoverbeek, 2020-11-14:
This looks OK. What options did you specify in the media center install script?
Could you also list your /boot/config.txt?

Danish-Food-Informatics, 2020-11-15:
@tvoverbeek, thank you for taking your time with this detective job :-)

I made a fresh installation of the Raspberry Pi OS (it automatically updates and installs the most recent files), and I used the installation script:

sudo su -c "bash <(wget -qO- https://pisupp.ly/mediacentersoftware)" root

The options used in the script are as follows:

Rotation: 270
Layout  : 1. TFT output only
Activate the console on the TFT display: Y
Install fbcp (Framebuffer Copy): N
Install xinput-calibrator: N
Enable onboard Joystick/Buttons: N
Configure MCR IR Remote: N
Reboot system now: Y

The content of the /boot/config.txt is very sparse:

disable_overscan=1
dtparam=audio=off

[All]
dtoverlay=media-center,speed=32000000,rotate=270

the rest of the file is commented out, either in the original file or by me as the entries had no effect on the display, like I commented out the two lines with dtoverlay and max_framebuffers below

[pi4]
# Enable DRM VC4 V3D driver on top of the dispmanx display stack
#dtoverlay=vc4-fkms-v3d
#max_framebuffers=2

However, the problem still exists.

Thanks again!

Danish-Food-Informatics, 2020-11-15:
Sorry for the headline above. The text should have been

# Enable DRM VC4 V3D driver on top of the dispmanx display stack
#dtoverlay=vc4-fkms-v3d
#max_framebuffers=2

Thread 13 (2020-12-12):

Media Centre HAT not working on RPi4 with Buster

ojtramp, 2020-12-12:
I've tried setting up the Media Centre HAT but cannot get the TFT screen to function at all. The touch control works out of the box and the rotation of the touch controls also functions after the setup but I haven't seen anything on the screen itself.

I've had a go using the [Pi Supply tutorials][1], and the ones referenced [here][2].

Originally I tried to set this up in Ubuntu (not officially supported) but have also not managed to get it working with Raspberry Pi OS Lite/Normal/Full, LibreELEC and even the latest image from [here][3].

The only error I see when the script runs is:
`E: Unable to locate package rbp-userland-dev-osmc` but on the OSMC website it says that it hasnt been updated for the Raspberry Pi 4, and Pi Supply say that they have tested their setup on Buster and say that this HAT is compatible with the Raspberry Pi 4 **so I think this is an optional package?** I have been unable to find a repository to install it on my device.

On the Raspberry Pi configuration settings I've enabled all interfaces (apart from SSH) to see if that made any difference but it didn't.

Any help people have on this would be great! In theory this is meant to be easy so I have no idea how I've managed to make it so complicated.

<hr>

***OS and Kernel Version***

    pi@raspberrypi:~ $ cat /etc/os-release
    PRETTY_NAME="Raspbian GNU/Linux 10 (buster)"
    NAME="Raspbian GNU/Linux"
    VERSION_ID="10"
    VERSION="10 (buster)"
    VERSION_CODENAME=buster
    ID=raspbian
    ID_LIKE=debian
    HOME_URL="http://www.raspbian.org/"
    SUPPORT_URL="http://www.raspbian.org/RaspbianForums"
    BUG_REPORT_URL="http://www.raspbian.org/RaspbianBugs"
    pi@raspberrypi:~ $ uname -r
    5.4.79-v7l+

<hr>

***Pi Supply automated Script output***

    pi@raspberrypi:~ $ sudo su -c "bash <(wget -qO- https://pisupp.ly/mediacentersoftware)" root
    Hit:1 http://raspbian.raspberrypi.org/raspbian buster InRelease
    Hit:2 http://archive.raspberrypi.org/debian buster InRelease
    Reading package lists... Done
    Select one of the options below:
    [0] - Portrait
    [90] - Horizontal (Default)
    [180] - Portrait Reverse
    [270] - Horizontal Reverse
    Option: 90
    EEPROM Loaded
    --- /usr/share/X11/xorg.conf.d/ ---

    -layout TFT
    -layout HDMI (Select for fbcp use)
    -layout HDMITFT
    When -layout is not set in lightdm, the first is used: TFT
    Select your prefered layout:
    1. TFT Output Only
    2. HDMI Output Only (select for fbcp)
    3. HDMI(Primary) & TFT(extension)
    Option(1-3):2
    Activate the console on the TFT display? y/n n
    Install fbcp (Framebuffer Copy)? y/n y
    --- Installing fbcp ---
    Installing FBCP on OMSC
    Reading package lists... Done
    Building dependency tree
    Reading state information... Done
    E: Unable to locate package rbp-userland-dev-osmc
    Reading package lists... Done
    Building dependency tree
    Reading state information... Done
    build-essential is already the newest version (12.6).
    git is already the newest version (1:2.20.1-2+deb10u3).
    The following additional packages will be installed:
      cmake-data libjsoncpp1 librhash0 libuv1
    Suggested packages:
      cmake-doc ninja-build
    The following NEW packages will be installed:
      cmake cmake-data libjsoncpp1 librhash0 libuv1
    0 upgraded, 5 newly installed, 0 to remove and 0 not upgraded.
    Need to get 4,330 kB of archives.
    After this operation, 21.8 MB of additional disk space will be used.
    Get:1 http://raspbian.mirror.uk.sargasso.net/raspbian buster/main armhf cmake-data all 3.13.4-1 [1,476 kB]
    Get:2 http://raspbian.mirror.uk.sargasso.net/raspbian buster/main armhf libjsoncpp1 armhf 1.7.4-3 [66.2 kB]
    Get:3 http://raspbian.mirror.uk.sargasso.net/raspbian buster/main armhf librhash0 armhf 1.3.8-1 [132 kB]
    Get:4 http://raspbian.mirror.uk.sargasso.net/raspbian buster/main armhf libuv1 armhf 1.24.1-1 [96.7 kB]
    Get:5 http://raspbian.mirror.uk.sargasso.net/raspbian buster/main armhf cmake armhf 3.13.4-1 [2,559 kB]
    Fetched 4,330 kB in 1s (4,309 kB/s)
    Selecting previously unselected package cmake-data.
    (Reading database ... 98393 files and directories currently installed.)
    Preparing to unpack .../cmake-data_3.13.4-1_all.deb ...
    Unpacking cmake-data (3.13.4-1) ...
    Selecting previously unselected package libjsoncpp1:armhf.
    Preparing to unpack .../libjsoncpp1_1.7.4-3_armhf.deb ...
    Unpacking libjsoncpp1:armhf (1.7.4-3) ...
    Selecting previously unselected package librhash0:armhf.
    Preparing to unpack .../librhash0_1.3.8-1_armhf.deb ...
    Unpacking librhash0:armhf (1.3.8-1) ...
    Selecting previously unselected package libuv1:armhf.
    Preparing to unpack .../libuv1_1.24.1-1_armhf.deb ...
    Unpacking libuv1:armhf (1.24.1-1) ...
    Selecting previously unselected package cmake.
    Preparing to unpack .../cmake_3.13.4-1_armhf.deb ...
    Unpacking cmake (3.13.4-1) ...
    Setting up libuv1:armhf (1.24.1-1) ...
    Setting up librhash0:armhf (1.3.8-1) ...
    Setting up cmake-data (3.13.4-1) ...
    Setting up libjsoncpp1:armhf (1.7.4-3) ...
    Setting up cmake (3.13.4-1) ...
    Processing triggers for man-db (2.8.5-2) ...
    Processing triggers for libc-bin (2.28-10+rpi1) ...
    Cloning into 'rpi-fbcp'...
    remote: Enumerating objects: 7, done.
    remote: Counting objects: 100% (7/7), done.
    remote: Compressing objects: 100% (5/5), done.
    remote: Total 7 (delta 1), reused 6 (delta 1), pack-reused 0
    Unpacking objects: 100% (7/7), done.
    -- The C compiler identification is GNU 8.3.0
    -- The CXX compiler identification is GNU 8.3.0
    -- Check for working C compiler: /usr/bin/cc
    -- Check for working C compiler: /usr/bin/cc -- works
    -- Detecting C compiler ABI info
    -- Detecting C compiler ABI info - done
    -- Detecting C compile features
    -- Detecting C compile features - done
    -- Check for working CXX compiler: /usr/bin/c++
    -- Check for working CXX compiler: /usr/bin/c++ -- works
    -- Detecting CXX compiler ABI info
    -- Detecting CXX compiler ABI info - done
    -- Detecting CXX compile features
    -- Detecting CXX compile features - done
    -- Configuring done
    -- Generating done
    -- Build files have been written to: /tmp/rpi-fbcp/build
    Scanning dependencies of target fbcp
    [ 50%] Building C object CMakeFiles/fbcp.dir/main.c.o
    [100%] Linking C executable fbcp
    [100%] Built target fbcp
    Enable automatic startup of fbcp on boot? y/n y
    Note: The console output on the TFT display will be disabled.
    Install xinput-calibrator? y/n n
    Enable onboard Joystick/Buttons? y/n n
    Configure MCH IR Remote? y/n n
    Reboot the system now? y/n

  [1]: https://github.com/PiSupply/Media-Center-HAT
  [2]: https://learn.watterott.com/hats/rpi-display/fbtft-install/
  [3]: https://learn.watterott.com/hats/rpi-display/sd-image/

tvoverbeek, 2020-12-12:
On raspberry-Pi-OS you should not see a reference to OSMC when installing fbcp.
You have the main display output on HDMI and rely on fbcp to copy it to the TFT display.
Is fbcp runing?
To test start it manually 'sudo fbcp &'

ojtramp, 2020-12-12:
So I dont think it's running on startup, I've added my /boot/config.txt below.
When I run the command sudo fbcp &, it returns [1] PID as below.

pi@raspberrypi:~ $ sudo fbcp &
[1] 1328

**/boot/config/.txt**
```

# For more options and information see
# http://rpf.io/configtxt
# Some settings may impact device functionality. See link above for details

# uncomment if you get no picture on HDMI for a default "safe" mode
#hdmi_safe=1

# uncomment this if your display has a black border of unused pixels visible
# and your display can output without overscan
#disable_overscan=1

# uncomment the following to adjust overscan. Use positive numbers if console
# goes off screen, and negative if there is too much border
#overscan_left=16
#overscan_right=16
#overscan_top=16
#overscan_bottom=16

# uncomment to force a console size. By default it will be display's size minus
# overscan.
#framebuffer_width=1280
#framebuffer_height=720

# uncomment if hdmi display is not detected and composite is being output
#hdmi_force_hotplug=1

# uncomment to force a specific HDMI mode (this will force VGA)
#hdmi_group=1
#hdmi_mode=1

# uncomment to force a HDMI mode rather than DVI. This can make audio work in
# DMT (computer monitor) modes
#hdmi_drive=2

# uncomment to increase signal to HDMI, if you have interference, blanking, or
# no display
#config_hdmi_boost=4

# uncomment for composite PAL
#sdtv_mode=2

#uncomment to overclock the arm. 700 MHz is the default.
#arm_freq=800

# Uncomment some or all of these to enable the optional hardware interfaces
dtparam=i2c_arm=on
#dtparam=i2s=on
dtparam=spi=on

# Uncomment this to enable infrared communication.
#dtoverlay=gpio-ir,gpio_pin=17
#dtoverlay=gpio-ir-tx,gpio_pin=18

# Additional overlays and parameters are documented /boot/overlays/README

# Enable audio (loads snd_bcm2835)
dtparam=audio=on

[pi4]
# Enable DRM VC4 V3D driver on top of the dispmanx display stack
dtoverlay=vc4-fkms-v3d
max_framebuffers=2

[all]
#dtoverlay=vc4-fkms-v3d
start_x=1
gpu_mem=128
enable_uart=1
dtoverlay=w1-gpio

```

ojtramp, 2020-12-12:
So I've managed to fix it.

I went through the manual process again and had to add a few stages / install some drivers / etc. I used the instructions from this [link](https://github.com/ssvb/xf86-video-fbturbo/wiki/Installation) to get the display drivers I needed.
```
sudo apt-get install git build-essential xorg-dev xutils-dev x11proto-dri2-dev
sudo apt-get install libltdl-dev libtool automake libdrm-dev
git clone https://github.com/ssvb/xf86-video-fbturbo.git
cd xf86-video-fbturbo
autoreconf -vi
./configure --prefix=/usr
make
sudo make install
sudo cp xorg.conf /etc/X11/xorg.conf
```

I then edited the configuration files at these locations (they're slightly different from the ones listed in the manual guide).

```
sudo nano /etc/X11/xorg.conf
sudo nano /etc/lightdm/lightdm.conf
```

Hope that helps someone work out where the automated script is going wrong for me (hopefully It was just a unique issue to me, but if not maybe this will help!).

mutipg, 2022-04-06:
I'm not good in Linux, but I'm trying do my best. I still have a problem with start Media Centre HAT on RPi4 with Buster.
- I had installed it with automated script,
- I also make steps from post above https://github.com/PiSupply/Media-Center-HAT/issues/13#issuecomment-743909451
- `sudo apt-get update` + `sudo apt-get upgrade`

After that Media Center HAT is probably working fine because after Ctrl+Alt+F2 I can see console, but it cannot start 'startx'. I see only blinking cursor on screen. I attached also Xorg log file - there is a line which IMO could be helpful:
`[    10.864] (EE) Screen 0 deleted because of no matching config section.`

@ojtramp, you wrote above:
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

Could you help me and give me a hint what did you changed in these files? My files looks like below and I can't find what to change in them.

---
### OS and Kernel Version
```
cat /etc/os-release
PRETTY_NAME="Raspbian GNU/Linux 10 (buster)"
NAME="Raspbian GNU/Linux"
VERSION_ID="10"
VERSION="10 (buster)"
VERSION_CODENAME=buster
ID=raspbian
ID_LIKE=debian
HOME_URL="http://www.raspbian.org/"
SUPPORT_URL="http://www.raspbian.org/RaspbianForums"
BUG_REPORT_URL="http://www.raspbian.org/RaspbianBugs"
```
---
### /etc/X11/xorg.conf
```
Section "Device"
        Identifier      "Allwinner A10/A13 FBDEV"
        Driver          "fbturbo"
        Option          "fbdev" "/dev/fb0"

        Option          "SwapbuffersWait" "true"
EndSection
```
---
### /etc/lightdm/lightdm.conf
```
#
# General configuration
#
# start-default-seat = True to always start one seat if none are defined in the configuration
# greeter-user = User to run greeter as
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

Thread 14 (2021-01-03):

Touch Screen not funcitoning

ojtramp, 2021-01-03:
Hi everyone

I am not getting any response from the resistive touch screen and am not sure what is wrong. I have installed the drivers as I have described in my previous issue regarding being unable display anything on the screen [here](https://github.com/PiSupply/Media-Center-HAT/issues/13), and then installed the screen via the automated script.

I am successfully using fbcp to mirror my HDMI output on Raspberry Pi OS 32-bit 2020-12-02.

The touchscreen is registered by the system but when I launch evtest it is not registering any input when I touch the screen.

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

I am also not getting any output using the following command `sudo cat /dev/input/event4`, but am on my other inputs.

Any help in getting this to work would be great!

Thanks

Ollie

shawaj, 2021-01-03:
@ojtramp can you try adding `dtoverlay=media-center,speed=32000000,rotate=0` to the /boot/config.txt

ojtramp, 2021-01-03:
Thanks shawaj but unfortunately it already has the line below:
`dtoverlay=media-center,speed=32000000,rotate=270`

shawaj, 2021-01-03:
Ah ok, can you try adding `dtoverlay=` right at the top of the file.

This will stop the overlay on the eeprom from loading.

Also is your RasPi fully updated?

ojtramp, 2021-01-03:
Doesn't seem to change anything unfortunately, still no output on evtest.

I've copied the whole of my config.txt, I've tried commenting out the line `doverlay=vc4-fkms-v3d`but that doesn't allow input from the touchscreen.

The RasPi is fully updated (sudo apt-get update and sudo apt-get upgrade).

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

shawaj, 2021-01-03:
@ojtramp sorry I think I didn't make myself clear.

At the top of the file you should put `dtoverlay=` just that text by itself.

At the bottom you should have `dtoverlay=media-center,speed=32000000,rotate=270`

ojtramp, 2021-01-03:
Oops! Sorry I misunderstood. I've made the corrections but unfortunately still nothing with evtest

shawaj, 2021-01-03:
@ojtramp could you just try a config.txt with:

```
dtoverlay=
disable_overscan=1
dtparam=audio=on
dtparam=spi=on
dtoverlay=vc4-fkms-v3d
max_framebuffers=2
dtoverlay=media-center,speed=32000000,rotate=270
```

First you should back up the old one and then create a new one:
```
mv /boot/config.txt /boot.config.old
nano /boot/config.txt
```

Then ctrl x, y and enter to save

ojtramp, 2021-01-03:
So the screen is now mirroring my HDMI again but still no touch input registered by evtest

shawaj, 2021-01-03:
I missed `dtparam=i2c_arm=on` from the above. Have edited.

ojtramp, 2021-01-03:
No problem, updated and rebooted. Can still see the screen but still no touch input registered by evtest.

shawaj, 2021-01-03:
Hmm, maybe try reseating the screen FPC cable in its connector?

Otherwise I'm out of ideas and inclined to say maybe it's a faulty display or touch controller.

Maybe @tvoverbeek or @ryanteck might have some other ideas?

ojtramp, 2021-01-03:
Happy to reseat the FPC cable but might wait until there are any other ideas (I've got no idea what I'm doing so dont want to cause any damage until its the last resort).

Thanks for your help though! Appreciate it

shawaj, 2021-01-03:
@ojtramp it shouldn't be too difficult to do. You just pull the two black bits shown in the below image, gently, away from the white part (in opposite direction to blue arrows)

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

And then pull out the gold/brown cable, then line it up as straight as you can and then push the black clips back in.

Could you share a photo of the top and bottom of the device as close up and high res as you can?

ojtramp, 2021-01-03:
You're right, that wasn't too bad. Unfortunately still no luck.

Here are some images, happy to retake if you need them to be more in focus.

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

ojtramp, 2021-01-06:
Any other ideas or shall I contact PiSupply for a replacement device?

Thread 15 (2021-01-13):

No output to Media-Center Hat after install.sh

barrettap, 2021-01-13:
After running install.sh, no output to display'
Actions:-
- Pi3B+ running headless. boot from USB memory stick
- Fit Media Center Hat.  Install PiOS Lite from Raspberry Pi Imager.
- ssh and perform apt-get update/upgrade.

- use instructions at https://learn.pi-supply.com/make/getting-started-with-the-media-center-hat/

- run cmd   sudo su -c "bash <(wget -qO- https://pisupp.ly/mediacentersoftware)" root

Problem
Discrepancy from the screen displays shown in the instructions. After entering 90 to the first question, I was shown the following messages:-

EEPROM Loaded
X Server not installed
Activate the console on the TFT display? y/n
--- /usr/share/x11/xorg.conf.d/ ---
    thru to
Option(1-3):
SO I DID NOT SEE THE LINES AND GET THE CHANCE TO SPECIFY TFT or HDMI or COMBINED OUTPUT
- n to the Activate the console... question.
- n to the next 4 questions (Install fbcp, Install calibrator, Enable buttons, Configure IR Remote)

- sudo reboot.

Result, after reboot, nothing has been displayed on the TFT.
***********************************************************************
Google found me "Media Center Hat not working on RPi 3B+ and Raspberry Pi OS (Buster installed 2020-11-10)" and I show below the output from a couple of command referenced therein:-
pi@PiHole3B:~ $ apt policy raspberrypi-kernel
raspberrypi-kernel:
  Installed: 1.20210108-1
  Candidate: 1.20210108-1
  Version table:
 *** 1.20210108-1 500
        500 http://archive.raspberrypi.org/debian buster/main armhf Packages
        100 /var/lib/dpkg/status
pi@PiHole3B:~ $ uname -a
Linux PiHole3B 5.4.83-v7+ #1379 SMP Mon Dec 14 13:08:57 GMT 2020 armv7l GNU/Linu              x
***********************************************************************
- Ryantech at Pi-Supply suggested making dtoverlay  changes listed in issue# 11 (re Kernel 5.4)
- Made those changes.
- During boot, media center hat flashed white screen momentarily, and turned backlight on
- Nothing else appeared on screen, I expected CLI

- Plug HDMI screen in and boot output date and CLI on that screen

I seem to have the same problem as shown in issue #10

tvoverbeek, 2021-01-14:
Install procedure assumes you are running a desktop and an X-server. It uses X-server settings (or fbcopy to copy the HDMI to the TFT) to display on the TFT.
Start with the Raspberry-OS Desktop (Raspberry Pi OS (32-bit) the first entry on the Choose OS screen of the RPi imager.

barrettap, 2021-01-14:
Ok, will try that.
-------- Original message --------From: Ton van Overbeek <notifications@github.com> Date: 14/01/2021  13:21  (GMT+00:00) To: PiSupply/Media-Center-HAT <Media-Center-HAT@noreply.github.com> Cc: barrettap <barrett.ap@btinternet.com>, Author <author@noreply.github.com> Subject: Re: [PiSupply/Media-Center-HAT] No output to Media-Center Hat after install.sh (#15)
Install procedure assumes you are running a desktop and an X-server. It uses X-server settings (or fbcopy to copy the HDMI to the TFT) to display on the TFT.
Start with the Raspberry-OS Desktop (Raspberry Pi OS (32-bit) the first entry on the Choose OS screen of the RPi imager.

—You are receiving this because you authored the thread.Reply to this email directly, view it on GitHub, or unsubscribe.
[
{
"@context": "http://schema.org",
"@type": "EmailMessage",
"potentialAction": {
"@type": "ViewAction",
"target": "https://github.com/PiSupply/Media-Center-HAT/issues/15#issuecomment-760192654",
"url": "https://github.com/PiSupply/Media-Center-HAT/issues/15#issuecomment-760192654",
"name": "View Issue"
},
"description": "View this Issue on GitHub",
"publisher": {
"@type": "Organization",
"name": "GitHub",
"url": "https://github.com"
}
}
]

barrettap, 2021-01-14:
It works. Thank you.
I think the instructions should mention that PiOS Lite won't work.
I'm going to use this for PiHole, for which I understand Lite is sufficient.

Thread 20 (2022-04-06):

Media Centre HAT on RPi4 with Buster - not working

mutipg, 2022-04-06:
I'm not good in Linux, but I'm trying do my best. I still have a problem with start Media Centre HAT on RPi4 with Buster.
- I had installed it with automated script,
- I also make steps from post above https://github.com/PiSupply/Media-Center-HAT/issues/13#issuecomment-743909451
- `sudo apt-get update` + `sudo apt-get upgrade`

After that Media Center HAT is probably working fine because after Ctrl+Alt+F2 I can see console, but it cannot start 'startx'. I see only blinking cursor on screen. I attached also Xorg log file - there is a line which IMO could be helpful:
`[    10.864] (EE) Screen 0 deleted because of no matching config section.`

@ojtramp, you wrote above:
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

Could you help me and give me a hint what did you changed in these files? My files looks like below and I can't find what to change in them.

---
### OS and Kernel Version
```
cat /etc/os-release
PRETTY_NAME="Raspbian GNU/Linux 10 (buster)"
NAME="Raspbian GNU/Linux"
VERSION_ID="10"
VERSION="10 (buster)"
VERSION_CODENAME=buster
ID=raspbian
ID_LIKE=debian
HOME_URL="http://www.raspbian.org/"
SUPPORT_URL="http://www.raspbian.org/RaspbianForums"
BUG_REPORT_URL="http://www.raspbian.org/RaspbianBugs"
```
---
### /etc/X11/xorg.conf
```
Section "Device"
        Identifier      "Allwinner A10/A13 FBDEV"
        Driver          "fbturbo"
        Option          "fbdev" "/dev/fb0"

        Option          "SwapbuffersWait" "true"
EndSection
```
---
### /etc/lightdm/lightdm.conf
```
#
# General configuration
#
# start-default-seat = True to always start one seat if none are defined in the configuration
# greeter-user = User to run greeter as
# minimum-display-number = Minimum display number to use for X servers
# minimum-vt = First VT to run displays on
# lock-memory = True to prevent memory from being paged to disk
# user-authority-in-system-dir = True if session authority should be in the system location
# guest-account-script = Script to be run to setup guest account
# logind-check-graphical = True to on start seats that are marked as graphical by logind
# log-directory = Directory to log information to
# run-directory = Directory to put running state in
# cache-directory = Directory to cache to
# sessions-directory = Directory to find sessions
# remote-sessions-directory = Directory to find remote sessions
# greeters-directory = Directory to find greeters
# backup-logs = True to move add a .old suffix to old log files when opening new ones
# dbus-service = True if LightDM provides a D-Bus service to control it
#
[LightDM]
#start-default-seat=true
#greeter-user=lightdm
#minimum-display-number=0
#minimum-vt=7
#lock-memory=true
#user-authority-in-system-dir=false
#guest-account-script=guest-account
#logind-check-graphical=false
#log-directory=/var/log/lightdm
#run-directory=/var/run/lightdm
#cache-directory=/var/cache/lightdm
#sessions-directory=/usr/share/lightdm/sessions:/usr/share/xsessions:/usr/share/wayland-sessions
#remote-sessions-directory=/usr/share/lightdm/remote-sessions
#greeters-directory=$XDG_DATA_DIRS/lightdm/greeters:$XDG_DATA_DIRS/xgreeters
#backup-logs=true
#dbus-service=true

#
# Seat configuration
#
# Seat configuration is matched against the seat name glob in the section, for example:
# [Seat:*] matches all seats and is applied first.
# [Seat:seat0] matches the seat named "seat0".
# [Seat:seat-thin-client*] matches all seats that have names that start with "seat-thin-client".
#
# type = Seat type (local, xremote, unity)
# pam-service = PAM service to use for login
# pam-autologin-service = PAM service to use for autologin
# pam-greeter-service = PAM service to use for greeters
# xserver-backend = X backend to use (mir)
# xserver-command = X server command to run (can also contain arguments e.g. X -special-option)
# xmir-command = Xmir server command to run (can also contain arguments e.g. Xmir -special-option)
# xserver-config = Config file to pass to X server
xserver-layout=TFT
# xserver-allow-tcp = True if TCP/IP connections are allowed to this X server
# xserver-share = True if the X server is shared for both greeter and session
# xserver-hostname = Hostname of X server (only for type=xremote)
# xserver-display-number = Display number of X server (only for type=xremote)
# xdmcp-manager = XDMCP manager to connect to (implies xserver-allow-tcp=true)
# xdmcp-port = XDMCP UDP/IP port to communicate on
# xdmcp-key = Authentication key to use for XDM-AUTHENTICATION-1 (stored in keys.conf)
# unity-compositor-command = Unity compositor command to run (can also contain arguments e.g. unity-system-compositor -special-option)
# unity-compositor-timeout = Number of seconds to wait for compositor to start
# greeter-session = Session to load for greeter
# greeter-hide-users = True to hide the user list
# greeter-allow-guest = True if the greeter should show a guest login option
# greeter-show-manual-login = True if the greeter should offer a manual login option
# greeter-show-remote-login = True if the greeter should offer a remote login option
# user-session = Session to load for users
# allow-user-switching = True if allowed to switch users
# allow-guest = True if guest login is allowed
# guest-session = Session to load for guests (overrides user-session)
# session-wrapper = Wrapper script to run session with
# greeter-wrapper = Wrapper script to run greeter with
# guest-wrapper = Wrapper script to run guest sessions with
# display-setup-script = Script to run when starting a greeter session (runs as root)
# display-stopped-script = Script to run after stopping the display server (runs as root)
# greeter-setup-script = Script to run when starting a greeter (runs as root)
# session-setup-script = Script to run when starting a user session (runs as root)
# session-cleanup-script = Script to run when quitting a user session (runs as root)
# autologin-guest = True to log in as guest by default
# autologin-user = User to log in with by default (overrides autologin-guest)
# autologin-user-timeout = Number of seconds to wait before loading default user
# autologin-session = Session to load for automatic login (overrides user-session)
# autologin-in-background = True if autologin session should not be immediately activated
# exit-on-failure = True if the daemon should exit if this seat fails
#
[Seat:*]
#type=local
#pam-service=lightdm
#pam-autologin-service=lightdm-autologin
#pam-greeter-service=lightdm-greeter
#xserver-backend=
#xserver-command=X
#xmir-command=Xmir
#xserver-config=
xserver-layout=TFT
#xserver-allow-tcp=false
#xserver-share=true
#xserver-hostname=
#xserver-display-number=
#xdmcp-manager=
#xdmcp-port=177
#xdmcp-key=
#unity-compositor-command=unity-system-compositor
#unity-compositor-timeout=60
greeter-session=pi-greeter
greeter-hide-users=false
#greeter-allow-guest=true
#greeter-show-manual-login=false
#greeter-show-remote-login=true
#user-session=default
#allow-user-switching=true
#allow-guest=true
#guest-session=
#session-wrapper=lightdm-session
#greeter-wrapper=
#guest-wrapper=
display-setup-script=/usr/share/dispsetup.sh
#display-stopped-script=
#greeter-setup-script=
#session-setup-script=
#session-cleanup-script=
#autologin-guest=false
autologin-user=pi
#autologin-user-timeout=0
#autologin-in-background=false
#autologin-session=
#exit-on-failure=false

#
# XDMCP Server configuration
#
# enabled = True if XDMCP connections should be allowed
# port = UDP/IP port to listen for connections on
# listen-address = Host/address to listen for XDMCP connections (use all addresses if not present)
# key = Authentication key to use for XDM-AUTHENTICATION-1 or blank to not use authentication (stored in keys.conf)
# hostname = Hostname to report to XDMCP clients (defaults to system hostname if unset)
#
# The authentication key is a 56 bit DES key specified in hex as 0xnnnnnnnnnnnnnn.  Alternatively
# it can be a word and the first 7 characters are used as the key.
#
[XDMCPServer]
#enabled=false
#port=177
#listen-address=
#key=
#hostname=

#
# VNC Server configuration
#
# enabled = True if VNC connections should be allowed
# command = Command to run Xvnc server with
# port = TCP/IP port to listen for connections on
# listen-address = Host/address to listen for VNC connections (use all addresses if not present)
# width = Width of display to use
# height = Height of display to use
# depth = Color depth of display to use
#
[VNCServer]
#enabled=false
#command=Xvnc
#port=5900
#listen-address=
#width=1024
#height=768
#depth=8
```
---
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

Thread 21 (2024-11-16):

Media Hat Center due to FBCP will not work on Rasberry pi 5!

Omnipresent77, 2024-11-16:
"fbcp is not considered functional on a Raspberry Pi 5 as the underlying DispmanX API it relies on has been deprecated and is no longer available on newer Raspberry Pi models, including the Pi 5; therefore, using fbcp on a Pi 5 is not recommended."

Soo basically what is anything can replace it so small HAt style screens can work again directly plugged into the PI5?

Omnipresent77, 2024-11-16:
another google search
"for most applications, particularly on Raspberry Pi, the primary replacement for "fbcp" is "fbcp-ili9341" which is a more modern and actively maintained driver that leverages the KMS (Kernel Mode Setting) stack instead of the deprecated DispmanX API that older "fbcp" versions relied on; however, the specific replacement might depend on your display type and the platform you're using."

Can anybody test this and see if indeed there is a way to get the media center hat to work again?

Omnipresent77, 2024-11-16:
From the raspberry pi forums:
[Re: How does the Raspberry Pi 5B fit into the SPI display so that it can display a GUI?](https://forums.raspberrypi.com/viewtopic.php?t=358478#p2150069)

[Sat Oct 28, 2023 5:42 am](https://forums.raspberrypi.com/viewtopic.php?p=2150069&sid=7cacd9580de35bdfbb0126cbeda66518#p2150069)

    [jieweizero](https://forums.raspberrypi.com/memberlist.php?mode=viewprofile&u=418054&sid=7cacd9580de35bdfbb0126cbeda66518) wrote: [↑](https://forums.raspberrypi.com/viewtopic.php?p=2150040&sid=7cacd9580de35bdfbb0126cbeda66518#p2150040)
    Sat Oct 28, 2023 1:34 am
    Will fbcp be completely eliminated? What is the ideal replacement method for driving the secondary screen?

The fbcp will be completely eliminated. The program used something called DispmanX to copy the image that is displayed on the Raspberry Pi output to a framebuffer. Mostly this was used to copy to a SPI display.

The ideal replacement is to have a driver for the display that supports DRM (Direct Rendering Manager) and then it would be possible to display the Raspberry Pi OS GUI directly on the SPI display.

I don't know which displays currently have DRM drivers. The following posts, by aBUGSworstnightmare show the GUI on a SPI device.

[viewtopic.php?t=355870](https://forums.raspberrypi.com/viewtopic.php?t=355870)

Obviously not everyone is going to write their own driver, but it shows that it is possible."

So IS A 'Direct Rendering manager' driver coming for the Media center hat???

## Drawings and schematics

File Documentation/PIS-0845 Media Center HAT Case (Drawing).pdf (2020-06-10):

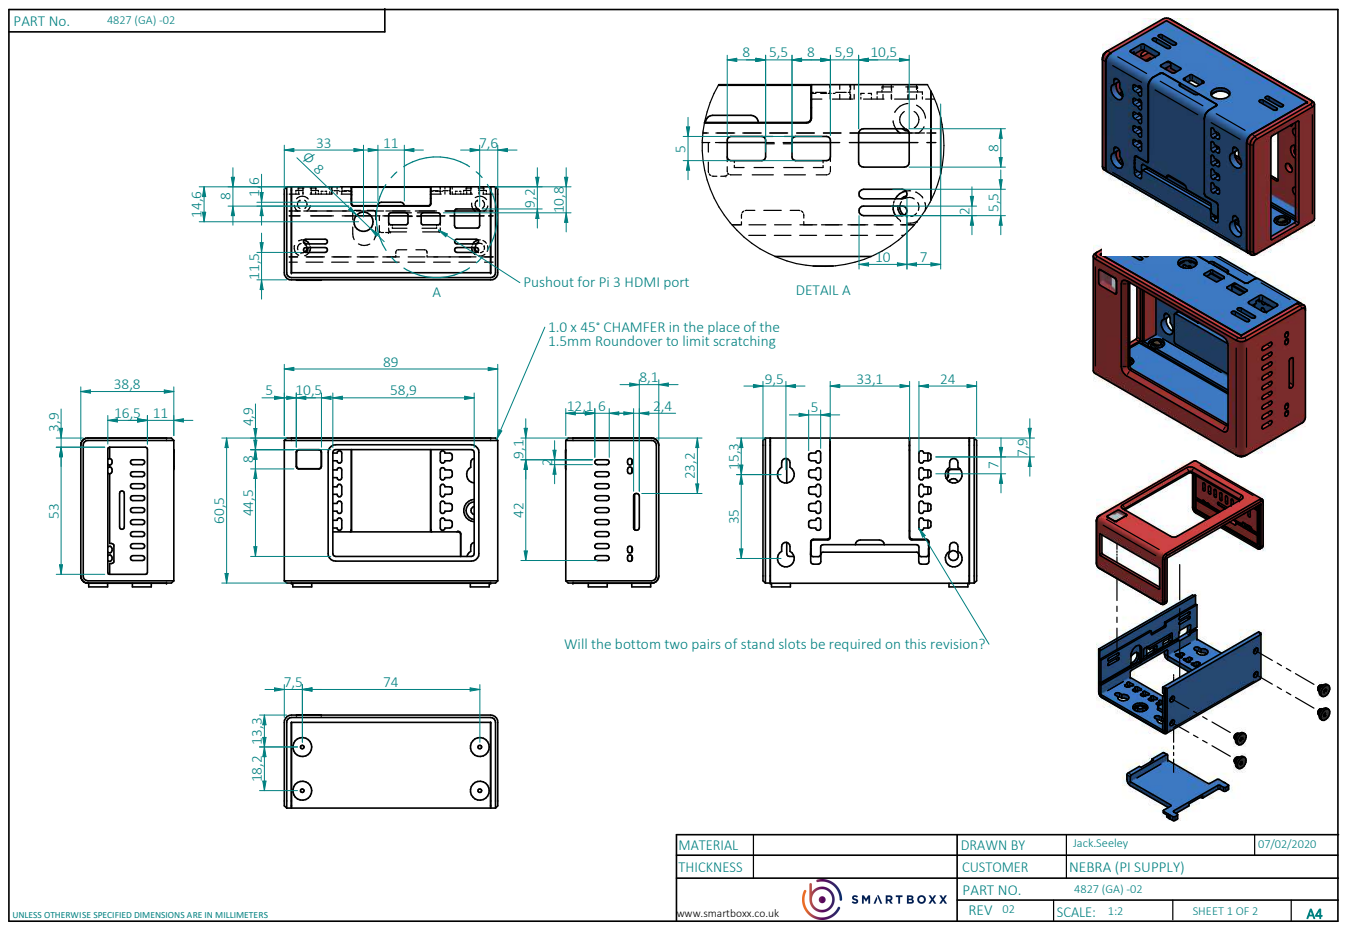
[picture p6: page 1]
UNLESS OTHERWISE SPECIFIED DIMENSIONS ARE IN MILLIMETERS; REV; SCALE:; SHEET 1 OF 2; PART No.; A DETAIL A

Pushout for Pi 3 HDMI port

1.0 x 45v CHAMFER in the place of the
1.5mm Roundover to limit scratching

Will the bottom two pairs of stand slots be required on this revision?

MATERIAL | DRAWN BY | Jack.Seeley | 07/02/2020
THICKNESS | CUSTOMER | NEBRA (PI SUPPLY)
www.smartboxx.co.uk | PART NO. 4827 (GA) -02

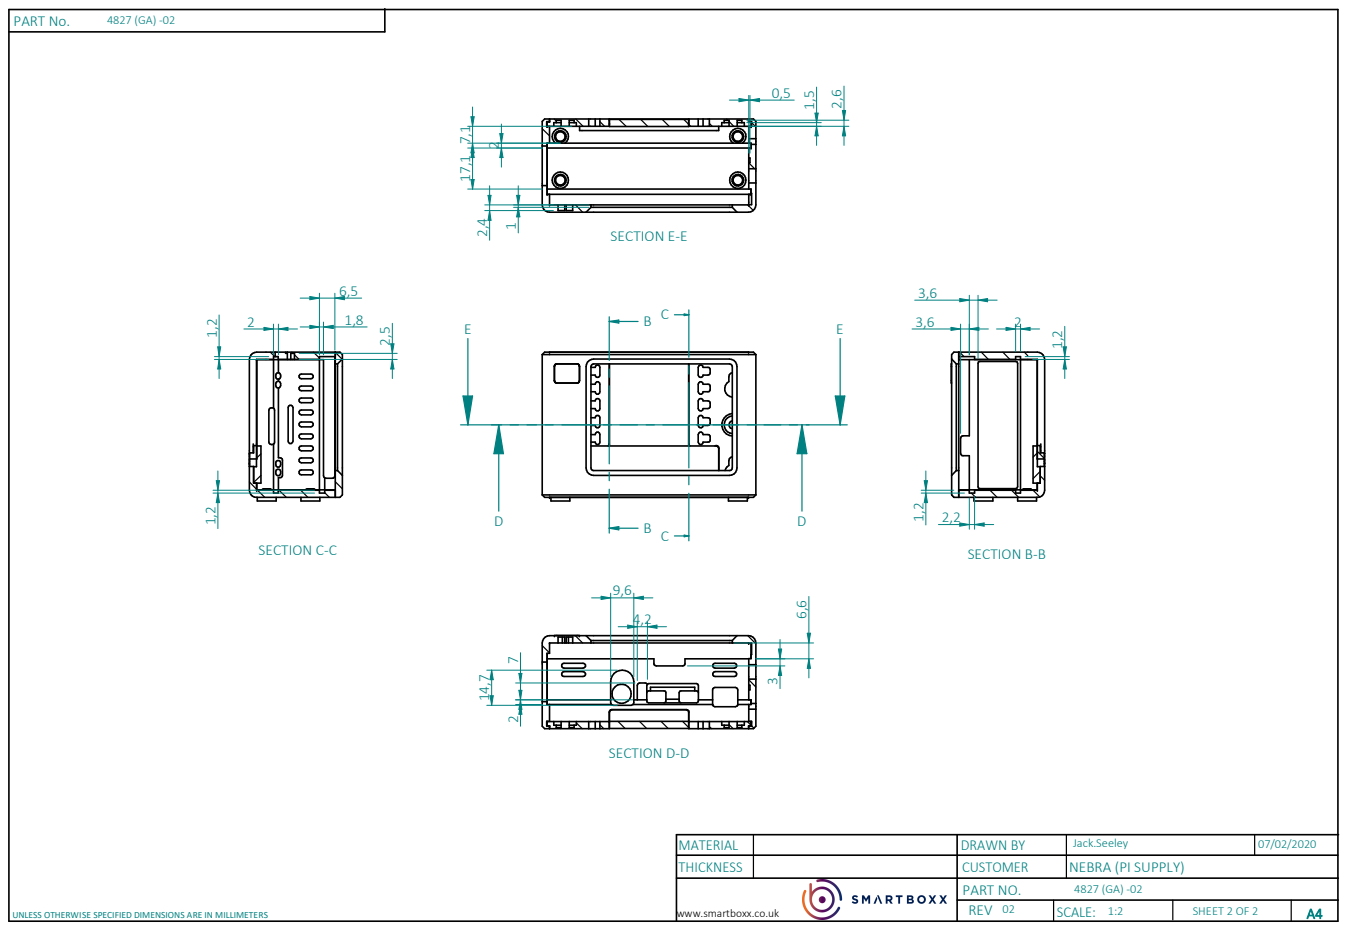
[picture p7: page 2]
UNLESS OTHERWISE SPECIFIED DIMENSIONS ARE IN MILLIMETERS; REV; SCALE:; SHEET 2 OF 2; PART No.; SECTION E-E; SECTION D-D; SECTION C-C; SECTION B-B

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

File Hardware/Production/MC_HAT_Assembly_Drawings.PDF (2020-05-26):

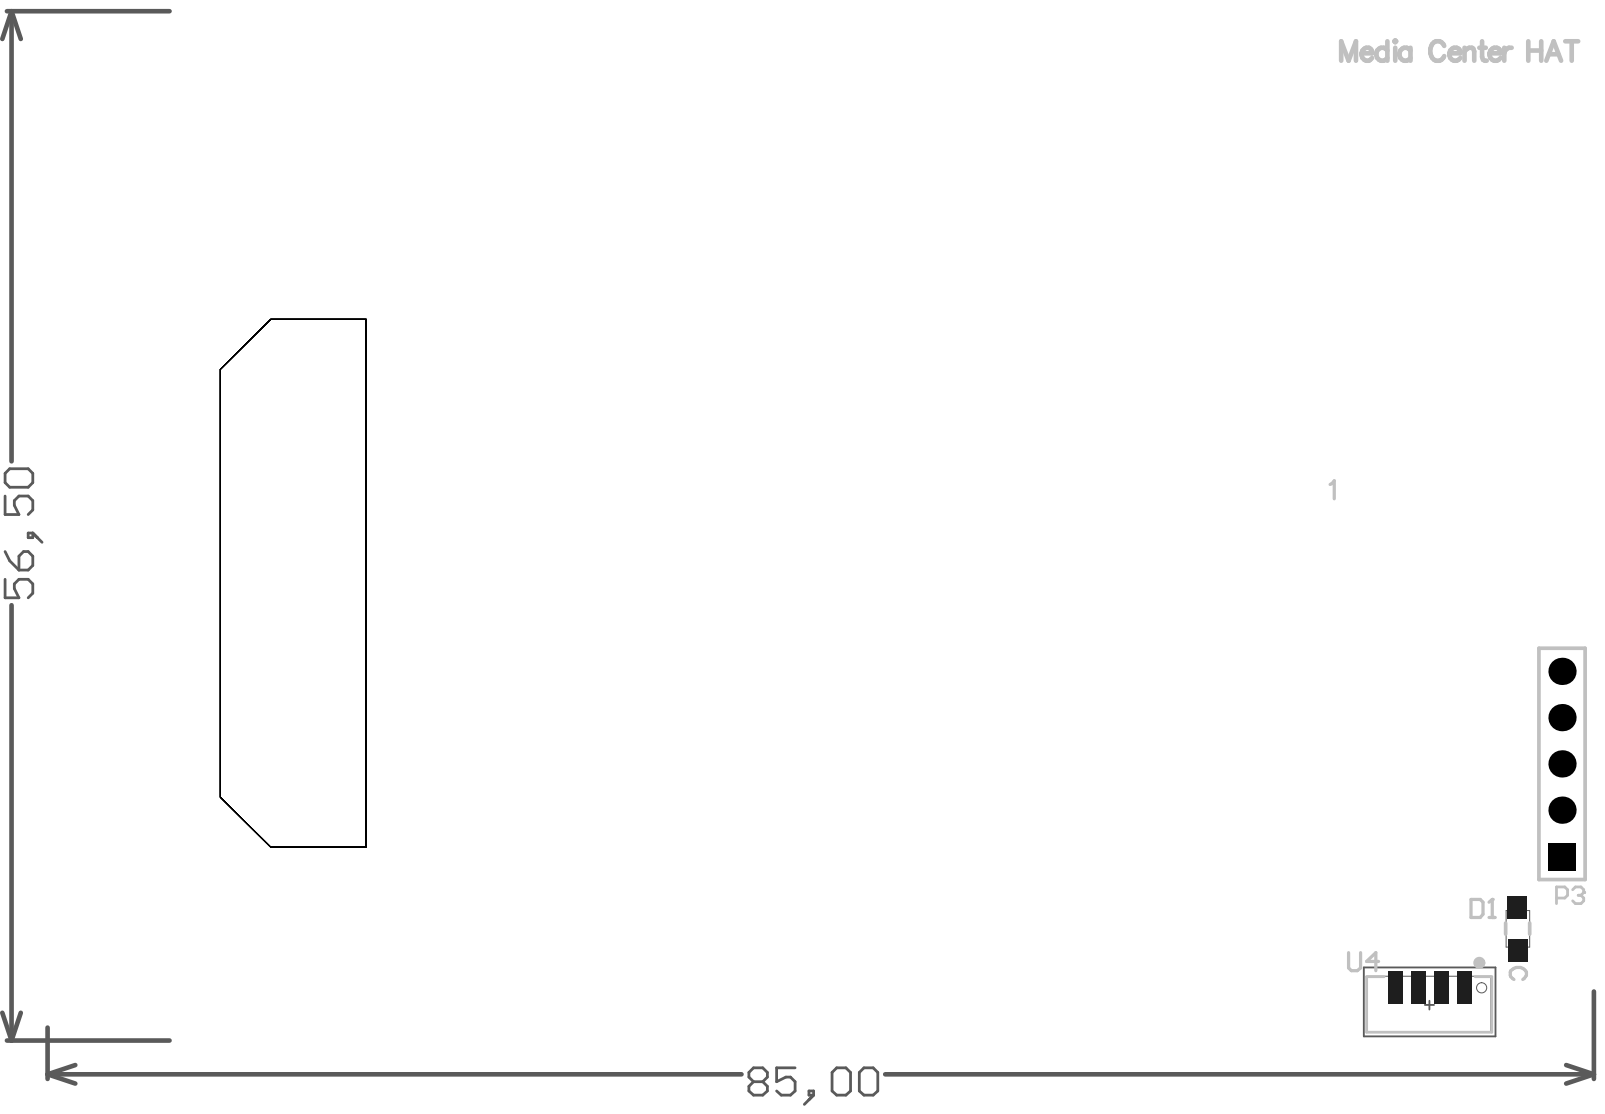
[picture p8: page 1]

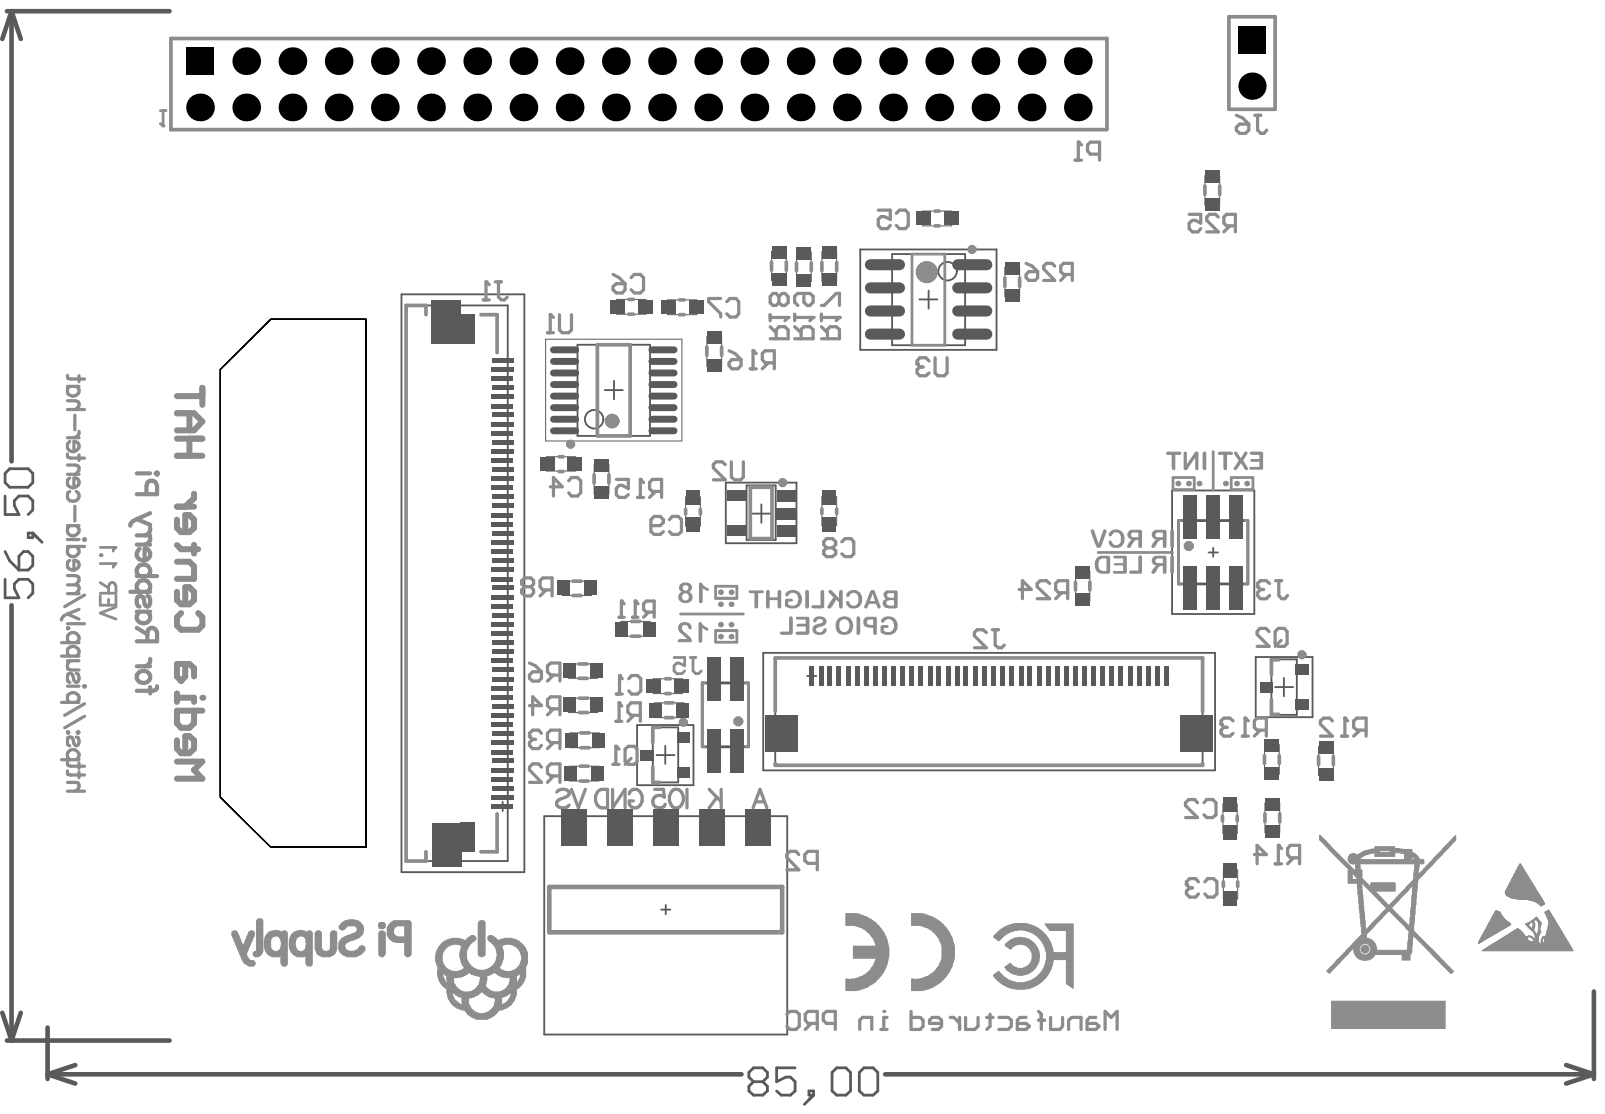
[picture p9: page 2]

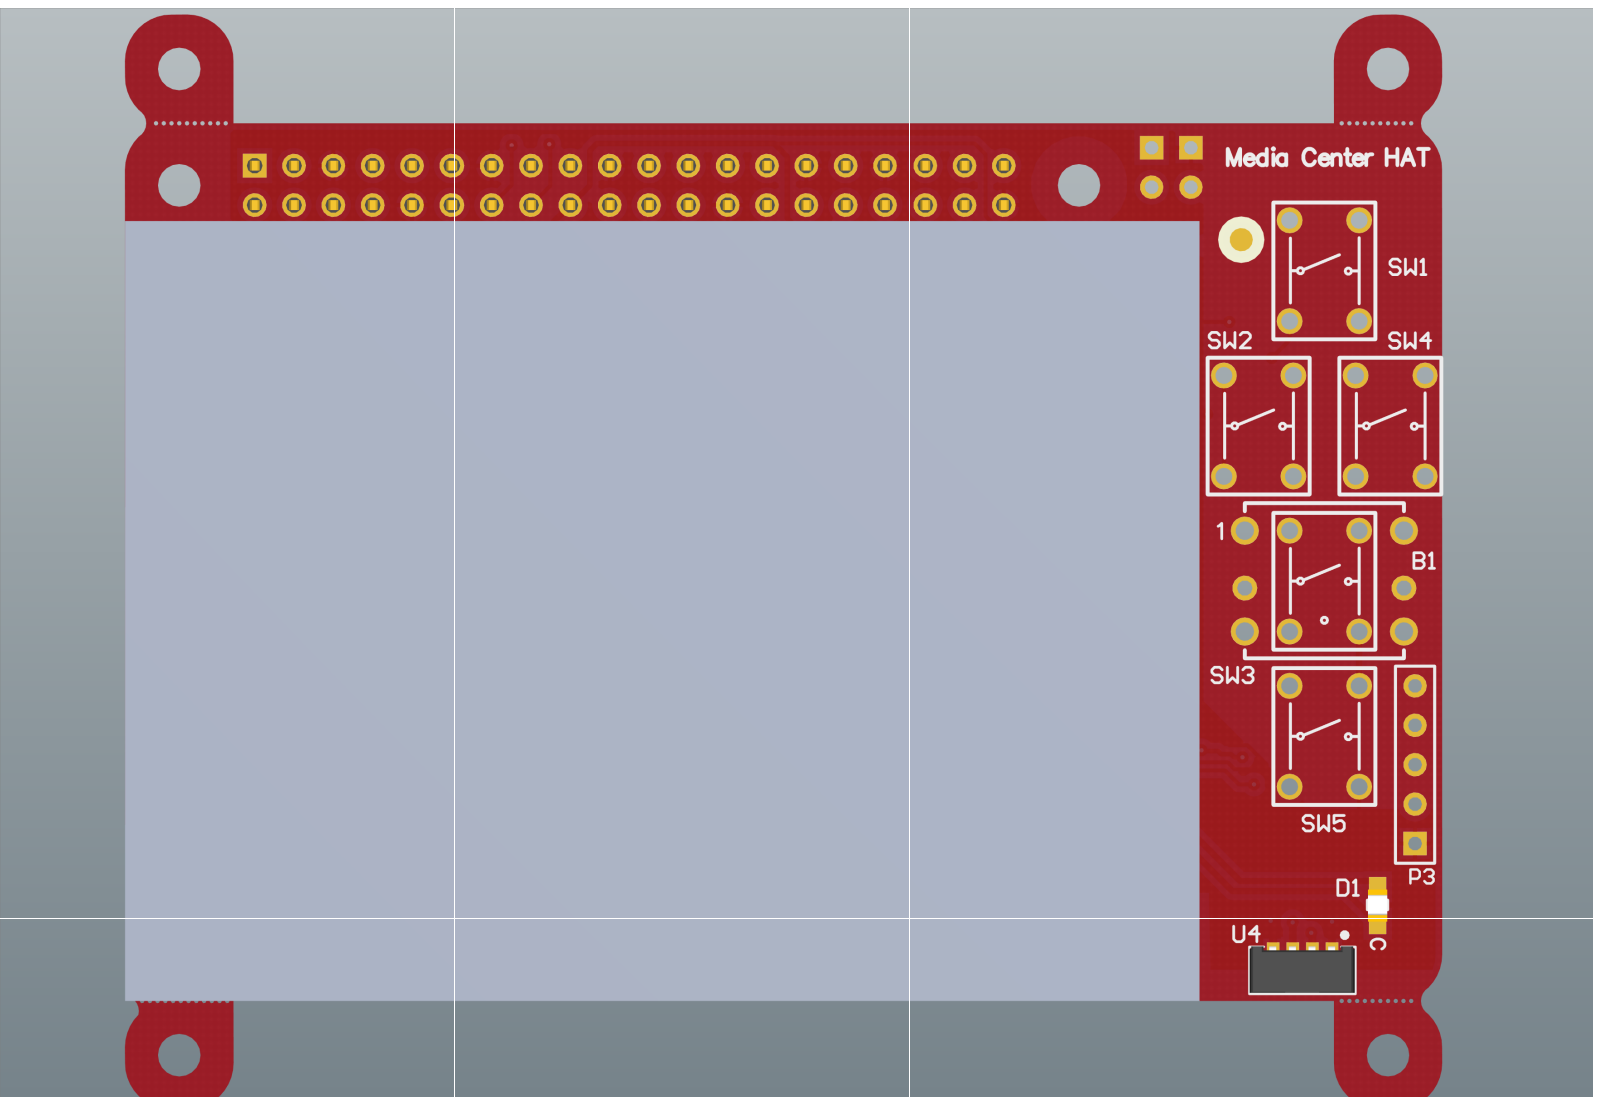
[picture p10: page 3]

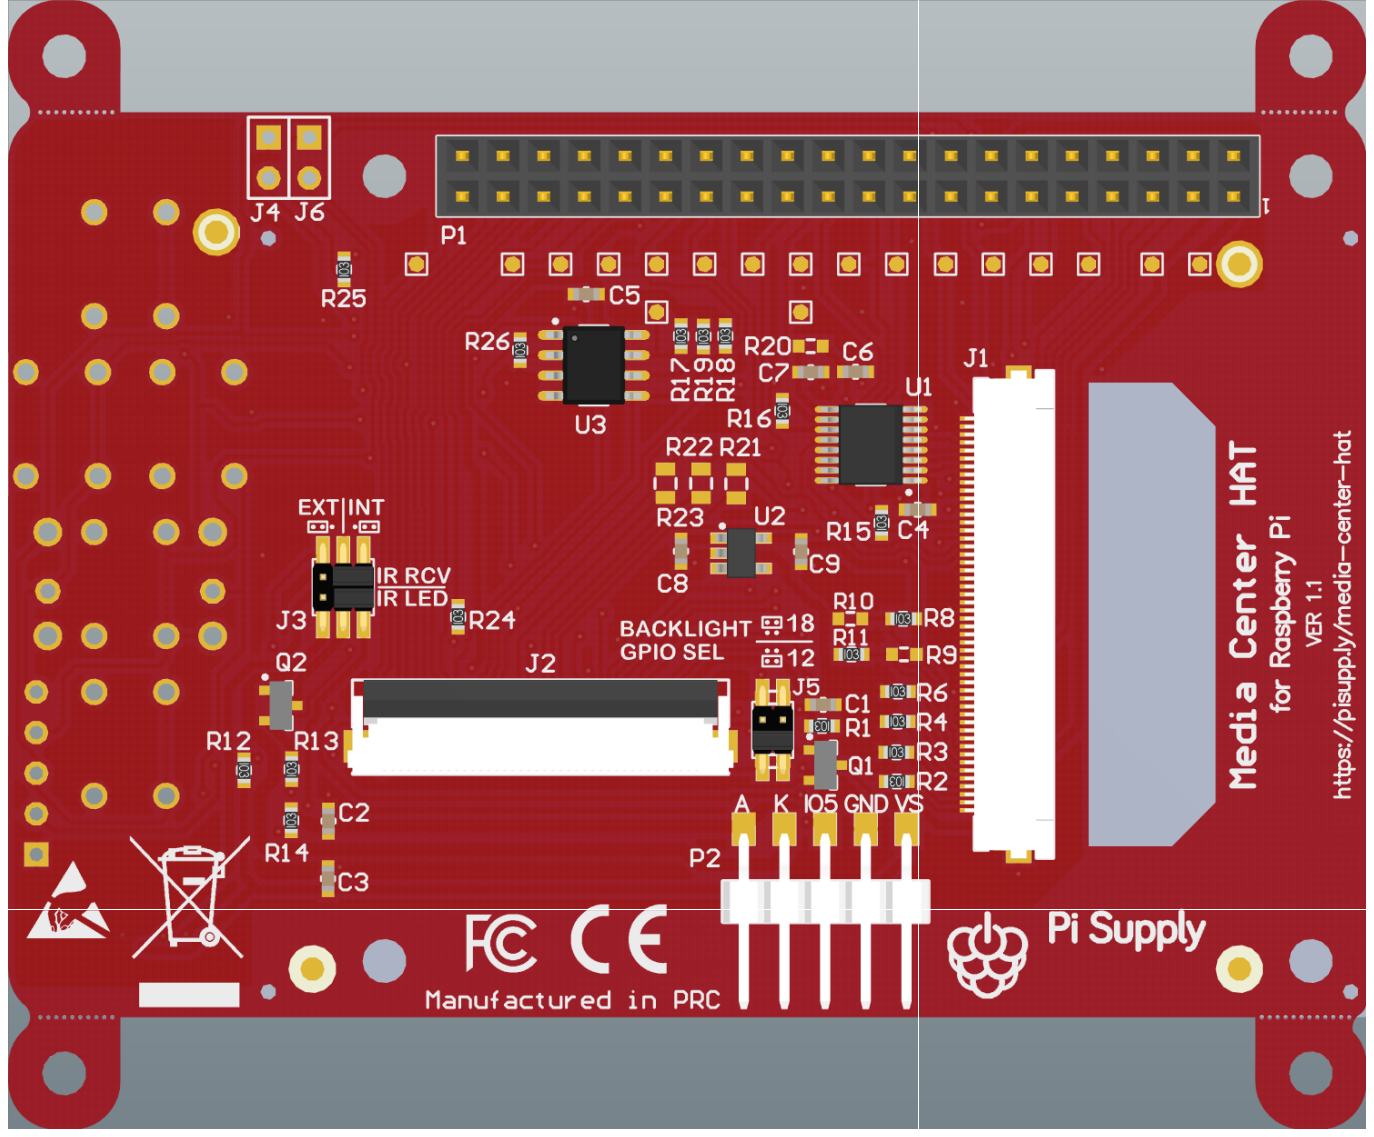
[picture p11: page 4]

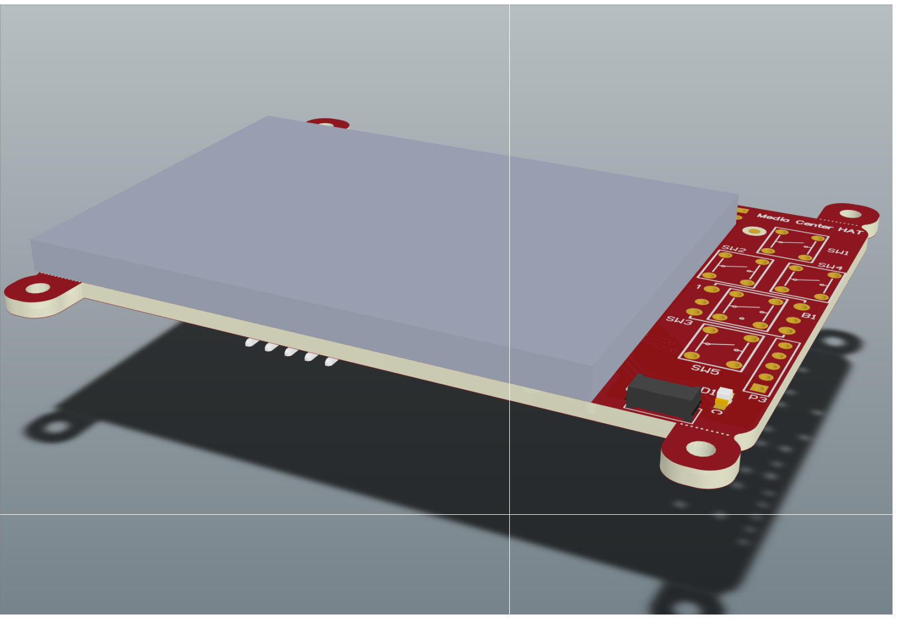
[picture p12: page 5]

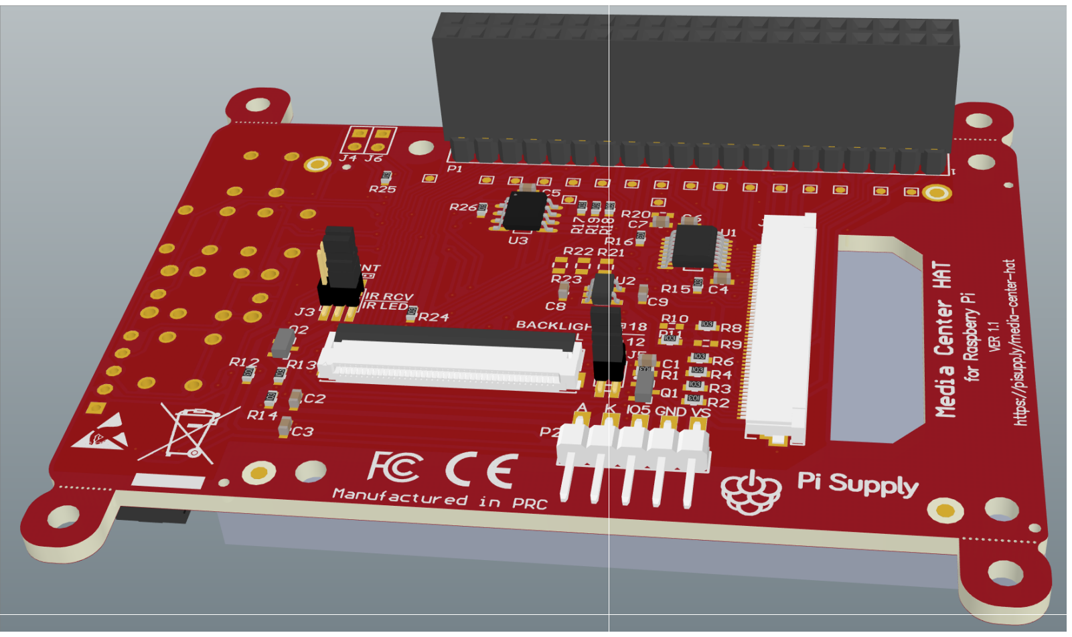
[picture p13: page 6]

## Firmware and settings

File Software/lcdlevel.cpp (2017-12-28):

//============================================================================
// Name        : lcdlevel.cpp
// Author      : Friedemann Wolpert and Aaron Shaw
// Version     : 1.0.0
// Forked from : https://github.com/watterott/RPi-Display/blob/master/docs/lcdlevel.cpp
// Copyright   : All Rights Reversed, based on wiringPi / Pi-blaster
// Description : Backlight control for Media Center HAT (Soft PWM Pin 12)
// Building :
//   * Install WiringPi: http://wiringpi.com/download-and-install/
//   * Compile: cc -o lcdlevel lcdlevel.cpp -lwiringPi -lpthread
//   * Set execution right: chmod +x lcdlevel
//============================================================================

//#include <iostream>
#include <stdio.h>
#include <stdlib.h>
#include <sys/types.h>
#include <sys/stat.h>
#include <getopt.h>
#include <unistd.h>

using namespace std;

#include "wiringPi.h"
#include "softPwm.h"

#define DEVFILE "/dev/lcdlevel"
//#define DEVFILE "/home/pi/lcd"

static char VERSION[] = "1.0.0";
static int lcdlevel = 100;

static void parseDevFileLoop(void);


void parseargs(int argc, char **argv)
{
  int index=0;
  int c;

  static struct option longopts[] =
  {
    {"help", no_argument, 0, 'h'},
    {"level", required_argument, 0, 'l'},
    {"version", no_argument, 0, 'v'},
    {0, 0, 0, 0}
  };

  while((c = getopt_long(argc, argv, "hl:v", longopts, &index )) != -1)
  {
    switch(c)
    {
      case 0:
        break;

      case 'h':
        fprintf(stderr, "%s version %s\n", argv[0], VERSION);
        fprintf(stderr, "Usage: %s [-hlv]\n"
                        "-h (--help)    - this information\n"
                        "-l (--level)   - set LCD Brightness 0 - 100%%\n"
                        "-v (--version) - version information\n"
                        "Example:\n"
                        "Usage : sudo ./lcdlevel -l 100\n"
                        "Update: echo \"99\" > /dev/lcdlevel\n"
                , argv[0]);
        exit(-1);

      case 'l':
        lcdlevel = atoi(optarg);
        break;

      case 'v':
        fprintf(stderr, "%s version %s\n", argv[0], VERSION);
        exit(-1);

      case '?':
        /* getopt_long already reported error? */
        exit(-1);

      default:
        exit(-1);
    }
  }
  }


int main(int argc, char **argv)
{
  // "sudo ./lcdlevel -l 0...100"
  parseargs(argc, argv);

  unlink(DEVFILE);

  if(mkfifo(DEVFILE, 0666) < 0)
  {
    printf("LCDLevel: Failed to open: %s: %m\n", DEVFILE);
    exit(0);
  }

  if(chmod(DEVFILE, 0666) < 0)
  {
    printf("LCDLevel: Failed to set permissions on: %s: %m\n", DEVFILE);
    exit(0);
  }

  printf("Setup LCD GPIO\n");
  wiringPiSetupGpio();

  if(lcdlevel>100) lcdlevel=100;
  if(lcdlevel<0)   lcdlevel=0;

  printf("CreateSoftPWM: %i\n", lcdlevel);

  softPwmCreate(12, lcdlevel, 100);

  // Read Brightness from file
  parseDevFileLoop();

  return 0;
}


// echo "20" > /dev/lcdlevel
static void parseDevFileLoop(void)
{
  FILE *fp;

  if((fp = fopen(DEVFILE, "r+")) == NULL)
  {
    printf("lcdlevel: Failed to open %s: %m\nCannot update display brightness\n", DEVFILE);
  }

  char *lineptr = NULL;
  size_t linelen;

  for(;;)
  {
    int n, value;

    if((n = getline(&lineptr, &linelen, fp)) < 0)
    {
      continue;
    }

    if (n > 4 )
    {
      fprintf(stderr, "Bad input: %s", lineptr);
    }

    value = atoi(lineptr);

    if ( (value >= 0)  && (value <= 100 ))
    {
      lcdlevel=value;
      softPwmWrite(12, lcdlevel);
    }
  }
}

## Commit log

2017-12-27 update dts with new configurable led and add dtbo
    update dts with new configurable led and add dtbo
2018-01-03 add button notes
    add button notes
2018-01-29 First commit of documentation rework
    [lcdlevel.cpp]
2018-02-21 Added information about overlays Configurations of buttons and joystick Touchscreen calibration
2018-02-21 Added Joystick/Buttons config in install script
2018-02-23 Added point and shoot camera first draft
2018-06-18 add button and alternative joystick headsheets
    add button and alternative joystick headsheets
2020-05-26 add files
    add files
    [MC_HAT_Assembly_BOM.xls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]
2020-06-10 Documentation
    - Added Media Center HAT Case drawing and 3D model
2022-01-17 Fix overlay for current buster kernel 5.10.x
    The overlay in the EEPROM is for kernel 4.x and soes not ork on later kernels.
    The one in github (and current Raspberry Pi OS buster distribution) is for jernel 5.4.x.
    It basically works , but the backlight is off -> black screen.
    Use the overlay from this commit for the current 5.10.x buster kernel.
    Note: TFT displays are not supported (et) in bullseye
